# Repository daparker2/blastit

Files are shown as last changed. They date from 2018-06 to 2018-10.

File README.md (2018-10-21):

# blastit
OBD2 UART-based display controller done in Verilog and C based on a Cyclone3 core board and custom display.

Basically this addresses issues I had in my last OBD2 gauge panel thing like the display being too bright and reset times being too slow. Image of my final rev C board below as I test the display:

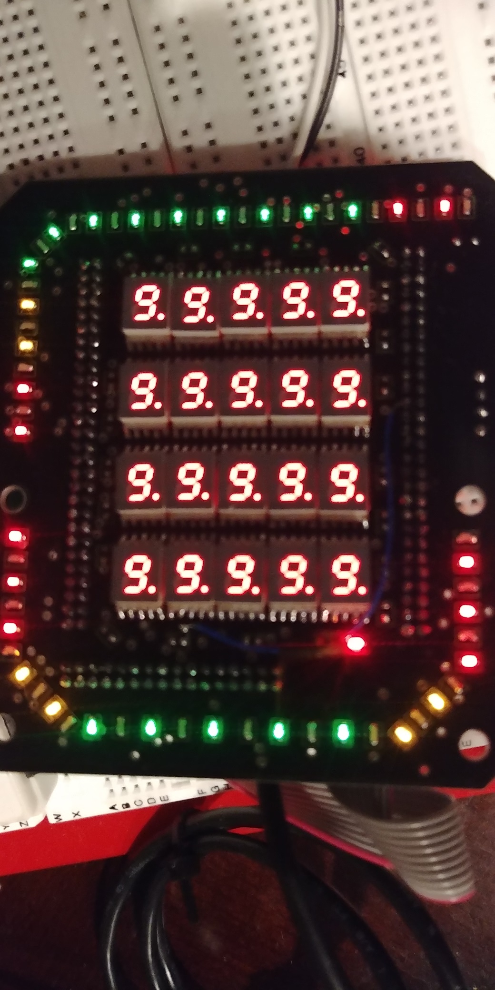
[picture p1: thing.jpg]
The thing


There is a UART and power input on the back which goes to a [Freematics OBD2](https://freematics.com/pages/products/freematics-obd-ii-uart-adapter-mk2/) ELM327 interface, and I have brought up the UART and display code already. FPGA is a [Waveshare Core3](https://www.waveshare.com/product/fpga-tools/altera/core/coreep3c16.htm). The code is mine and display is a pretty simple [2-layer PCB](https://github.com/daparker2/blastit/blob/master/doc/RevC.PDF) with a couple LED matrix bars and a central 20 digit readout. Now I am just writing the display task engine and OBD2 state machine and then it will just need a final mechanical enclosure which I am 3D printing; I am not totally happy with the one I have already printed.

Maybe one more update if I ever get it in my car, I have an STL file which I have 3D printed before but I will need to modify the model to make the fitment closer to the PCB and to work with an existing gauge fixture I have, cause removing double sided tape last time I reinstalled a gauge really tore up my dashboard. Haha.

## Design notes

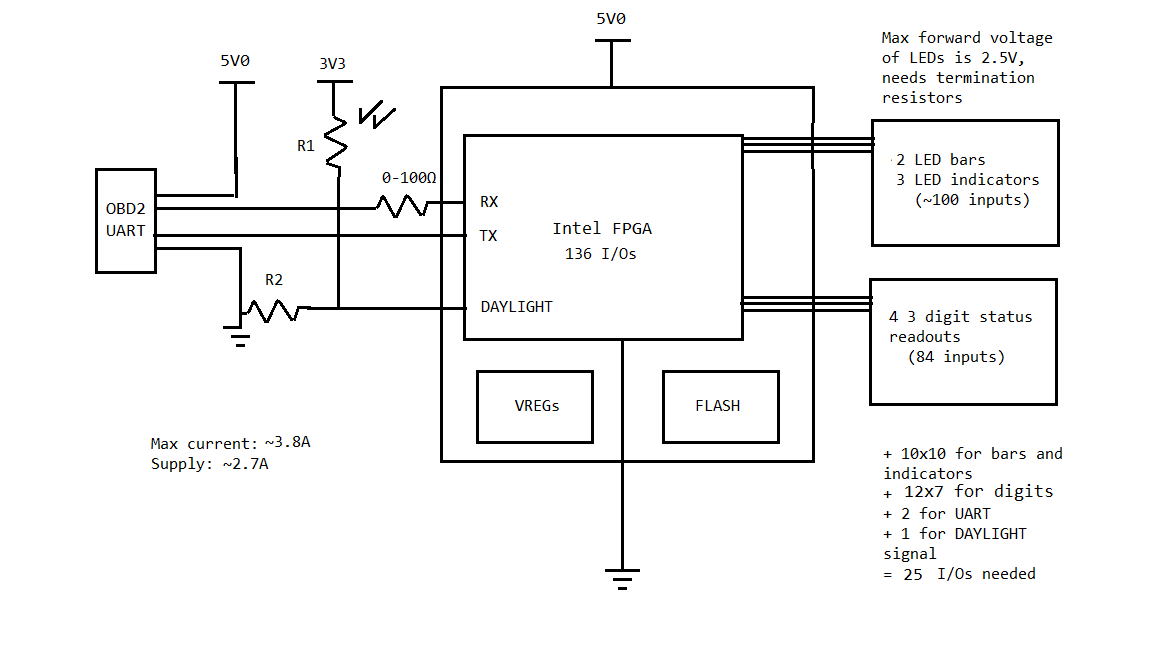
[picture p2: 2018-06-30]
doc/gauge2.png

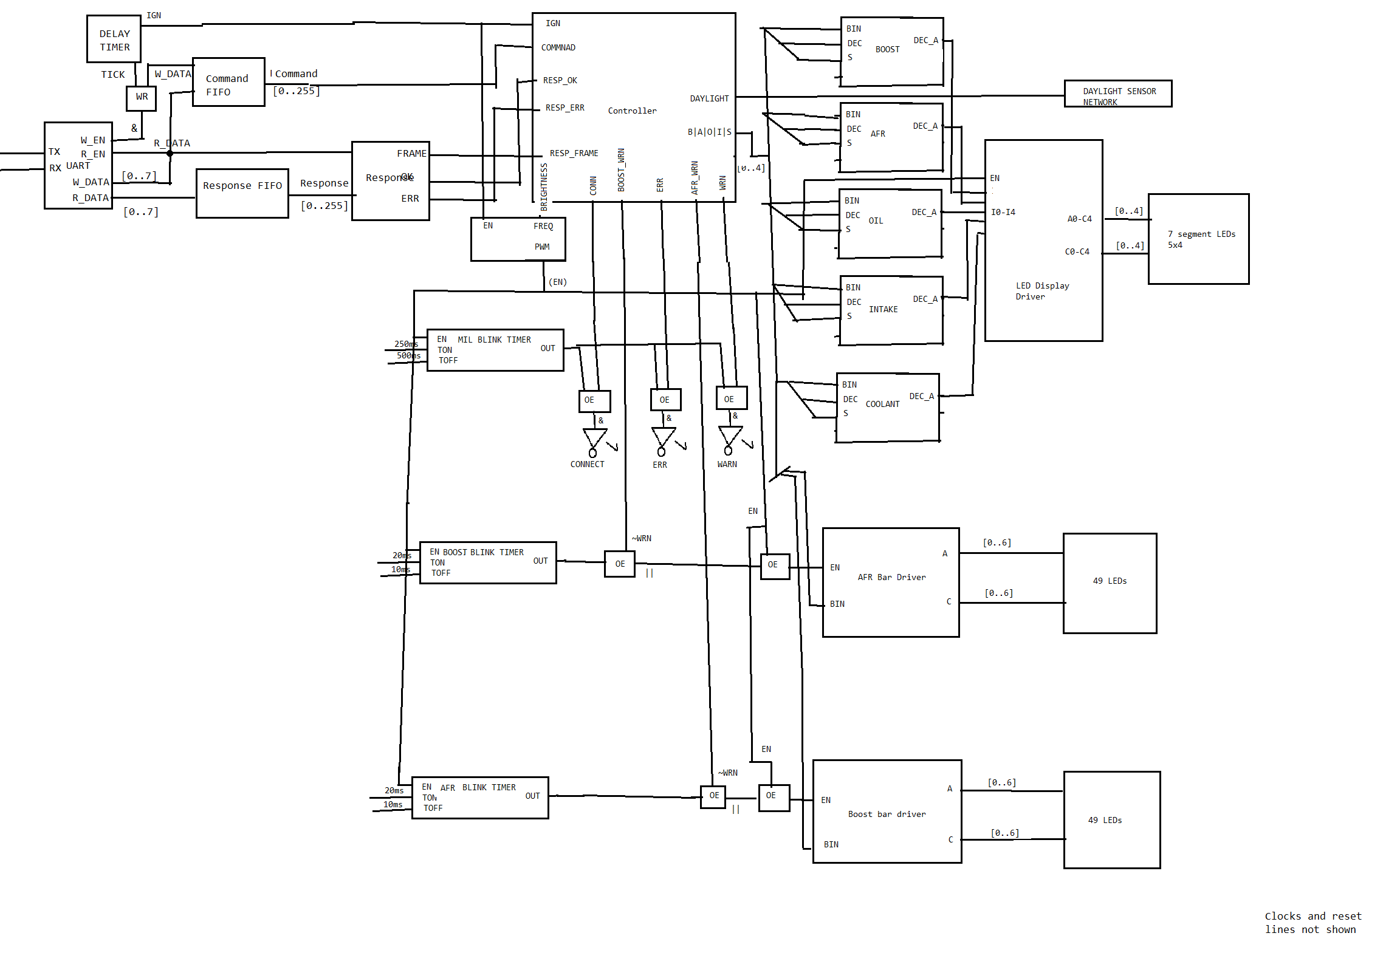
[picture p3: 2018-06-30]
doc/stack.png

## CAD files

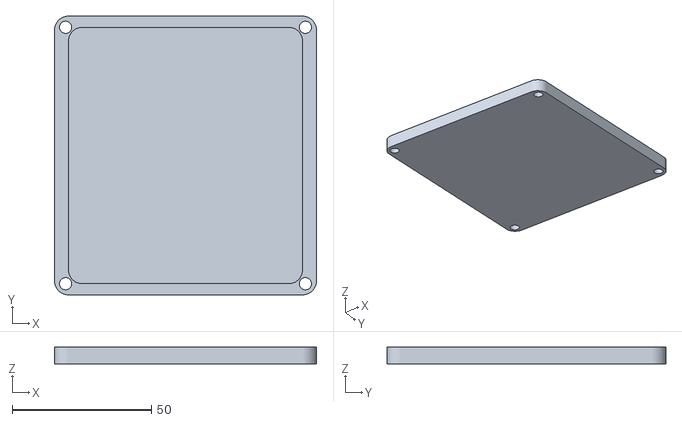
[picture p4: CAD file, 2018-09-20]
doc/Enclosure/Viewpane.stl
94.0 x 100.0 x 6.00

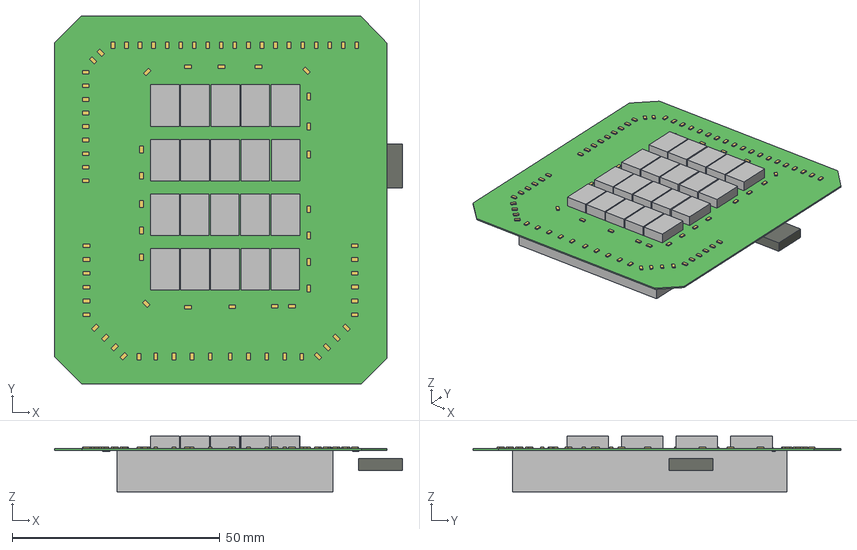
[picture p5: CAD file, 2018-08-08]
doc/RevC.step
83.7 x 88.5 x 13.4 mm
Board
Extruded x 111

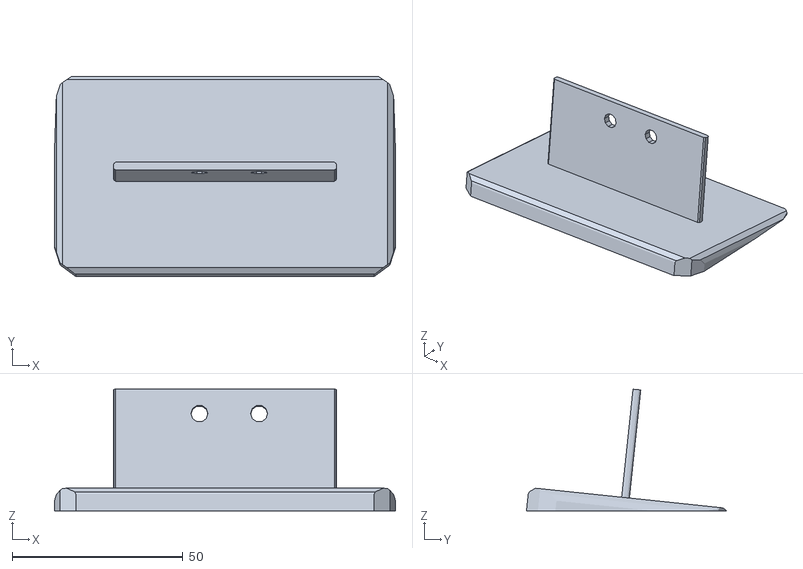
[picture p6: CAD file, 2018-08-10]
Enclosure/Base.stl
100.0 x 58.7 x 35.7

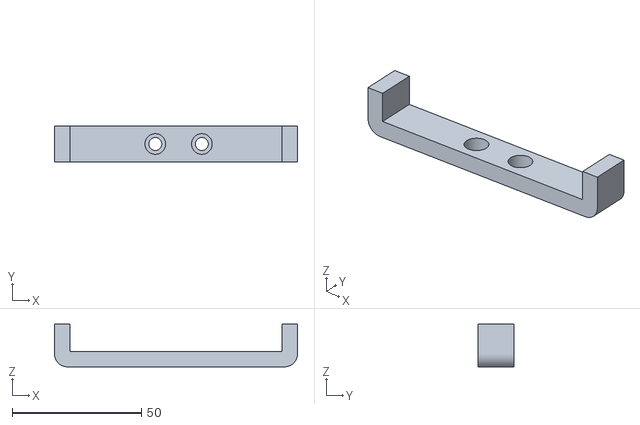
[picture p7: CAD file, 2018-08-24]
doc/Enclosure/Connector.stl
94.0 x 14.0 x 16.5

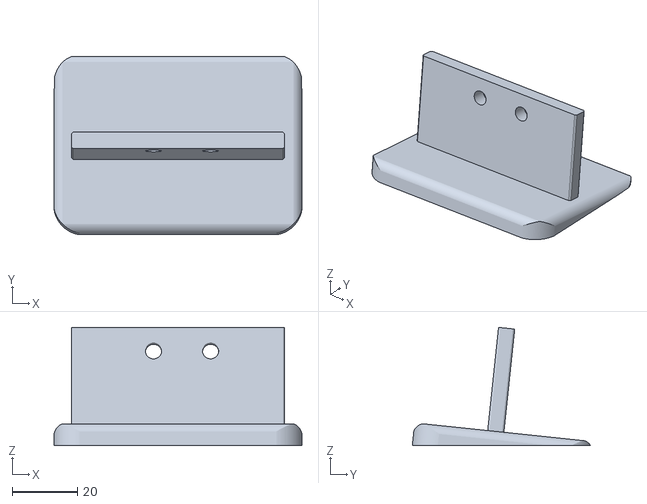
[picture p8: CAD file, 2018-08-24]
doc/Enclosure/Base.stl
76.0 x 54.7 x 36.2

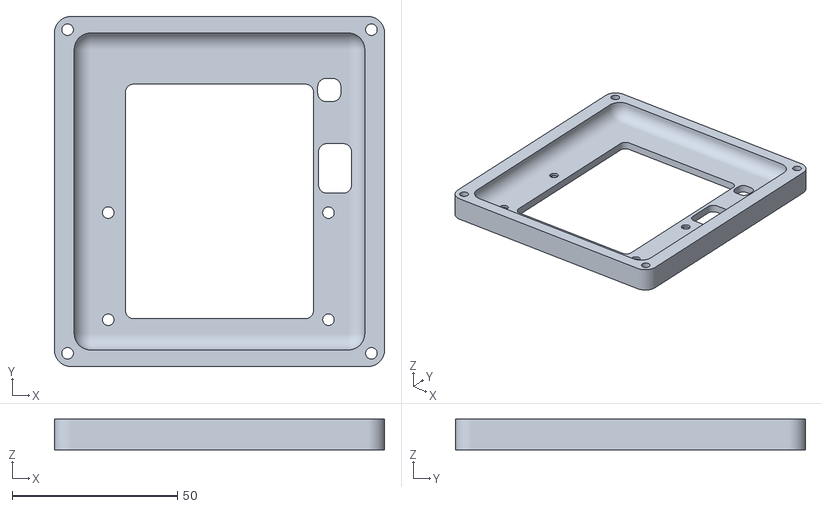
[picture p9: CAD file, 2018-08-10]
doc/Enclosure/Back.stl
100.0 x 106.0 x 9.38

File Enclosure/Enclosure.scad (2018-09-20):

// Module enclosure for proejct

// Subdivision resolution
FN_ROUND=200;
//FN_ROUND=10;
FN_HEX=6;

// Hex nut
HEX_NUT_WIDTH=7;
HEX_NUT_HEIGHT=3;

//PCB
PCB_OFFSET_Z=-6;

// PCB drill hole
PCB_HOLE_WIDTH=3.5;
PCB_HOLE_HEIGHT=50;
PCB_HOLE_OFFSET_X1=32;
PCB_HOLE_OFFSET_X2=34.7;
PCB_HOLE_OFFSET_Y1=-8.9;
PCB_HOLE_OFFSET_Y2=-41.33;

// Clamshell back
CLAMSHELL_INNER_X=74;
CLAMSHELL_INNER_Y=82;
CLAMSHELL_INNER_Z=5;
CLAMSHELL_OUTER_X=84;
CLAMSHELL_OUTER_Y=90;
CLAMSHELL_OUTER_Z=20;
CLAMSHELL_ROUND_W=10;
CLAMSHELL_BACK_Z=18;

// Clamshell back cutout
CLAMSHELL_CUTOUT1_X=5;
CLAMSHELL_CUTOUT1_Y=10;
CLAMSHELL_CUTOUT1_OFFSET_X=35;
CLAMSHELL_CUTOUT1_OFFSET_Y=7;
CLAMSHELL_CUTOUT2_X=52;
CLAMSHELL_CUTOUT2_Y=66;
CLAMSHELL_CUTOUT2_OFFSET_X=0;
CLAMSHELL_CUTOUT2_OFFSET_Y=-3;
CLAMSHELL_CUTOUT3_X=2;
CLAMSHELL_CUTOUT3_Y=2;
CLAMSHELL_CUTOUT3_OFFSET_X=33.25;
CLAMSHELL_CUTOUT3_OFFSET_Y=30.75;
CLAMSHELL_CUTOUT_ROUND_W=5;
CLAMSHELL_CUTOUT_Z=30;
CLAMSHELL_CUTOUT_OFFSET_Z=-10;
CLAMSHELL_VIEWPANE_SCALE_Z=5;
CLAMSHELL_CUTOUT_OFFSET_X=1;
CLAMSHELL_CUTOUT_OFFSET_Y=2.5;

// Clamshell viewpane drill holes
VIEWPANE_HOLE_WIDTH=3.5;
VIEWPANE_HOLE_HEIGHT=50;
VIEWPANE_HOLE_OFFSET_X1=43;
VIEWPANE_HOLE_OFFSET_X2=43;
VIEWPANE_HOLE_OFFSET_Y1=46;
VIEWPANE_HOLE_OFFSET_Y2=-46;
VIEWPANE_HOLE_SCALE = 1.25;
VIEWPANE_COVER_Z=1;
VIEWPANE_SKIRT_Z=3; // Skirt around ICs that are now sticking out...

// Clamshell front
CLAMSHELL_VIEWPANE_Z=3;

// Clamshell connector
CLAMSHELL_CONNECTOR_OUTER_X=CLAMSHELL_OUTER_X+.001;
CLAMSHELL_CONNECTOR_OUTER_Y=7;
CLAMSHELL_CONNECTOR_OUTER_Z=13;
CLAMSHELL_CONNECTOR_INNER_X=CLAMSHELL_CONNECTOR_OUTER_X-2;
CLAMSHELL_CONNECTOR_INNER_Y=CLAMSHELL_CONNECTOR_OUTER_Y+100;
CLAMSHELL_CONNECTOR_INNER_Z=CLAMSHELL_CONNECTOR_OUTER_Z+8;
CLAMSHELL_CONNECTOR_INNER_OFFSET_Z=5;
CLAMSHELL_CONNECTOR_OFFSET_X=0;
CLAMSHELL_CONNECTOR_OFFSET_Y=-27;
CLAMSHELL_CONNECTOR_OFFSET_Z=-12;
CLAMSHELL_CONNECTOR_CUTOFF_X=100;
CLAMSHELL_CONNECTOR_CUTOFF_Y=60;
CLAMSHELL_CONNECTOR_CUTOFF_Z=18;
CLAMSHELL_CONNECTOR_CUTOFF_OFFSET_Z=14;
CLAMSHELL_CONNECTOR_ROUND_W=5;

// Clamshell connector holes
CLAMSHELL_CONNECTOR_HOLE_OFFSET_X=-8;
CLAMSHELL_CONNECTOR_HOLE_OFFSET_Y=-30.5;
CLAMSHELL_CONNECTOR_HOLE_OFFSET_Z=-14;
CLAMSHELL_CONNECTOR_INNER_HOLE_H=100;
CLAMSHELL_CONNECTOR_INNER_HOLE_RADIUS=2.5;
CLAMSHELL_CONNECTOR_OUTER_HOLE_H=16;
CLAMSHELL_CONNECTOR_OUTER_HOLE_RADIUS=4;
CLAMSHELL_CONNECTOR_HOLE_WIDTH=18;

// Clamshell base
CLAMSHELL_BASE_ANGLE=84;
CLAMSHELL_BASE_OFFSET_X=-50;
CLAMSHELL_BASE_OFFSET_Y=-62;
CLAMSHELL_BASE_OFFSET_Z=-10;

// Demo
DEMO_BASE_ANGLE=84;

module board() {
	color("Green", 1.0) {
		translate([CLAMSHELL_CUTOUT_OFFSET_X,CLAMSHELL_CUTOUT_OFFSET_Y,PCB_OFFSET_Z]) {
			import("RevC.stl");
		}
	}
}

module base() {
	color("Magenta", 1.0) {
		translate([CLAMSHELL_BASE_OFFSET_X, CLAMSHELL_BASE_OFFSET_Y, CLAMSHELL_BASE_OFFSET_Z])
		rotate([-CLAMSHELL_BASE_ANGLE, 0, 0])
			import("Base.stl");
	}
}
		

// Drill hole 3d bodies
module drill_holes() {
	translate([PCB_HOLE_OFFSET_X1,0,-PCB_HOLE_HEIGHT/2]) {
		translate([0,PCB_HOLE_OFFSET_Y1,0])
			cylinder(r=PCB_HOLE_WIDTH/2, h=PCB_HOLE_HEIGHT, $fn=FN_ROUND);
		translate([0,PCB_HOLE_OFFSET_Y2,0])
			cylinder(r=PCB_HOLE_WIDTH/2, h=PCB_HOLE_HEIGHT, $fn=FN_ROUND);
	}

	translate([-PCB_HOLE_OFFSET_X2,0,-PCB_HOLE_HEIGHT/2]) {
		translate([0,PCB_HOLE_OFFSET_Y1,0])
			cylinder(r=PCB_HOLE_WIDTH/2, h=PCB_HOLE_HEIGHT, $fn=FN_ROUND);
		translate([0,PCB_HOLE_OFFSET_Y2,0])
			cylinder(r=PCB_HOLE_WIDTH/2, h=PCB_HOLE_HEIGHT, $fn=FN_ROUND);
	}
}

module hex_nut_holes() {
	translate([PCB_HOLE_OFFSET_X1,0,0]) {
		translate([0,PCB_HOLE_OFFSET_Y1,0])
			cylinder(r=HEX_NUT_WIDTH/2, h=HEX_NUT_HEIGHT, $fn=FN_HEX);
		translate([0,PCB_HOLE_OFFSET_Y2,0])
			cylinder(r=HEX_NUT_WIDTH/2, h=HEX_NUT_HEIGHT, $fn=FN_HEX);
	}

	translate([-PCB_HOLE_OFFSET_X2,0,0]) {
		translate([0,PCB_HOLE_OFFSET_Y1,0])
			cylinder(r=HEX_NUT_WIDTH/2, h=HEX_NUT_HEIGHT, $fn=FN_HEX);
		translate([0,PCB_HOLE_OFFSET_Y2,0])
			cylinder(r=HEX_NUT_WIDTH/2, h=HEX_NUT_HEIGHT, $fn=FN_HEX);
	}
}

module clamshell_inner_region() {
	minkowski() {
		cube([CLAMSHELL_INNER_X, CLAMSHELL_INNER_Y, CLAMSHELL_INNER_Z], center=true);
		sphere(r=CLAMSHELL_ROUND_W/2, center=true, $fn=FN_ROUND);
	}
}

module clamshell_outer_region() {
	minkowski() {
		cube([CLAMSHELL_OUTER_X, CLAMSHELL_OUTER_Y, CLAMSHELL_OUTER_Z], center=true);
		cylinder(r=CLAMSHELL_ROUND_W/2, center=true, $fn=FN_ROUND);
	}
}

module clamshell_viewpane_region(viewpane_z) {
	minkowski() {
		cube([CLAMSHELL_OUTER_X, CLAMSHELL_OUTER_Y, viewpane_z], center=true);
		cylinder(r=CLAMSHELL_ROUND_W/2, center=true, $fn=FN_ROUND);
	}
}

// Drill holes for clamshell viewpane
module viewpane_drill_holes(viewpane_hole_scale) {
	if (!viewpane_hole_scale) {
		translate([VIEWPANE_HOLE_OFFSET_X1,0,-VIEWPANE_HOLE_HEIGHT/2]) {
			translate([0,VIEWPANE_HOLE_OFFSET_Y1,0])
				cylinder(r=VIEWPANE_HOLE_WIDTH/2, h=VIEWPANE_HOLE_HEIGHT, $fn=FN_ROUND);
			translate([0,VIEWPANE_HOLE_OFFSET_Y2,0])
				cylinder(r=VIEWPANE_HOLE_WIDTH/2, h=VIEWPANE_HOLE_HEIGHT, $fn=FN_ROUND);
		}

		translate([-VIEWPANE_HOLE_OFFSET_X2,0,-VIEWPANE_HOLE_HEIGHT/2]) {
			translate([0,VIEWPANE_HOLE_OFFSET_Y1,0])
				cylinder(r=VIEWPANE_HOLE_WIDTH/2, h=VIEWPANE_HOLE_HEIGHT, $fn=FN_ROUND);
			translate([0,VIEWPANE_HOLE_OFFSET_Y2,0])
				cylinder(r=VIEWPANE_HOLE_WIDTH/2, h=VIEWPANE_HOLE_HEIGHT, $fn=FN_ROUND);
		}
	} else {
		translate([VIEWPANE_HOLE_OFFSET_X1,0,-VIEWPANE_HOLE_HEIGHT/2]) {
			translate([0,VIEWPANE_HOLE_OFFSET_Y1,0])
				cylinder(r=(VIEWPANE_HOLE_WIDTH*VIEWPANE_HOLE_SCALE)/2, h=VIEWPANE_HOLE_HEIGHT, $fn=FN_ROUND);
			translate([0,VIEWPANE_HOLE_OFFSET_Y2,0])
				cylinder(r=(VIEWPANE_HOLE_WIDTH*VIEWPANE_HOLE_SCALE)/2, h=VIEWPANE_HOLE_HEIGHT, $fn=FN_ROUND);
		}

		translate([-VIEWPANE_HOLE_OFFSET_X2,0,-VIEWPANE_HOLE_HEIGHT/2]) {
			translate([0,VIEWPANE_HOLE_OFFSET_Y1,0])
				cylinder(r=(VIEWPANE_HOLE_WIDTH*VIEWPANE_HOLE_SCALE)/2, h=VIEWPANE_HOLE_HEIGHT, $fn=FN_ROUND);
			translate([0,VIEWPANE_HOLE_OFFSET_Y2,0])
				cylinder(r=(VIEWPANE_HOLE_WIDTH*VIEWPANE_HOLE_SCALE)/2, h=VIEWPANE_HOLE_HEIGHT, $fn=FN_ROUND);
		}
	}
}

module clamshell_back_cutout_region() {
	union() {
		// This is for the OBD2 connection
		translate([CLAMSHELL_CUTOUT1_OFFSET_X, CLAMSHELL_CUTOUT1_OFFSET_Y, CLAMSHELL_CUTOUT_OFFSET_Z]) {
			minkowski() {
				cube([CLAMSHELL_CUTOUT1_X, CLAMSHELL_CUTOUT1_Y, CLAMSHELL_CUTOUT_Z], center=true);
				sphere(r=CLAMSHELL_CUTOUT_ROUND_W/2, center=true, $fn=FN_ROUND);
			}
		}
		
		// This relief area for the FPGA module
		translate([CLAMSHELL_CUTOUT2_OFFSET_X, CLAMSHELL_CUTOUT2_OFFSET_Y, CLAMSHELL_CUTOUT_OFFSET_Z]) {
			minkowski() {
				cube([CLAMSHELL_CUTOUT2_X, CLAMSHELL_CUTOUT2_Y, CLAMSHELL_CUTOUT_Z], center=true);
				sphere(r=CLAMSHELL_CUTOUT_ROUND_W/2, center=true, $fn=FN_ROUND);
			}
		}
		
		// This is for the daylight sensor to poke out
		translate([CLAMSHELL_CUTOUT3_OFFSET_X, CLAMSHELL_CUTOUT3_OFFSET_Y, CLAMSHELL_CUTOUT_OFFSET_Z]) {
			minkowski() {
				cube([CLAMSHELL_CUTOUT3_X, CLAMSHELL_CUTOUT3_Y, CLAMSHELL_CUTOUT_Z], center=true);
				sphere(r=CLAMSHELL_CUTOUT_ROUND_W/2, center=true, $fn=FN_ROUND);
			}
		}
	}
}

module clamshell_back() {
	color("Blue", 1) {
		difference() {
			clamshell_outer_region();
			clamshell_inner_region();
			translate([0,0,CLAMSHELL_BACK_Z/2])
			scale([1.05, 1.05, CLAMSHELL_VIEWPANE_SCALE_Z])
				clamshell_viewpane_region(CLAMSHELL_VIEWPANE_Z);			
			viewpane_drill_holes(false);
			clamshell_back_cutout_region();
			clamshell_connector();
			translate([CLAMSHELL_CUTOUT_OFFSET_X, CLAMSHELL_CUTOUT_OFFSET_Y, 0]) {
				drill_holes();
				translate([0,0,-(CLAMSHELL_OUTER_Z+HEX_NUT_HEIGHT)/2])
					hex_nut_holes();
			}
		}
	}
}

module clamshell_viewpane() {
	color("Yellow", 0.25) {
		translate([0,0,10]) {
			difference() {
				union() {
					clamshell_viewpane_region(VIEWPANE_COVER_Z);
					translate([0,0,VIEWPANE_SKIRT_Z - 0.001])
						difference() {
							clamshell_viewpane_region(VIEWPANE_SKIRT_Z);
			clamshell_inner_region();
						}
				}
				viewpane_drill_holes(true);
			}
		}
	}
}

module clamshell_connector_holes() {
	// Add speed holes...
	translate([CLAMSHELL_CONNECTOR_HOLE_OFFSET_X, CLAMSHELL_CONNECTOR_HOLE_OFFSET_Y, CLAMSHELL_CONNECTOR_HOLE_OFFSET_Z]) {	
		union() {
			cylinder(r=CLAMSHELL_CONNECTOR_INNER_HOLE_RADIUS,h=CLAMSHELL_CONNECTOR_INNER_HOLE_H, $fn=FN_ROUND, center=true);
			cylinder(r=CLAMSHELL_CONNECTOR_OUTER_HOLE_RADIUS,h=CLAMSHELL_CONNECTOR_OUTER_HOLE_H, $fn=FN_ROUND, center=true);
		}
		
		translate([CLAMSHELL_CONNECTOR_HOLE_WIDTH,0,0]) 
		union() {
			cylinder(r=CLAMSHELL_CONNECTOR_INNER_HOLE_RADIUS,h=CLAMSHELL_CONNECTOR_INNER_HOLE_H, $fn=FN_ROUND, center=true);
			cylinder(r=CLAMSHELL_CONNECTOR_OUTER_HOLE_RADIUS,h=CLAMSHELL_CONNECTOR_OUTER_HOLE_H, $fn=FN_ROUND, center=true);
		}
	}
}
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

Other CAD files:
FPGA/blastit_main.stp
Enclosure/RevC.step
Enclosure/RevC.stl

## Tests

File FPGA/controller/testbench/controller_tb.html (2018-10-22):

controller_tb

2018.10.21.20:50:07 | Datasheet

Overview

controller_inst_clk_0 | controller_tb

Processor
controller_inst_nios2e Nios II 13.1
All Components
controller_inst_sysid_c001 altera_avalon_sysid_qsys 13.1
controller_inst_jtag_uart_0 altera_avalon_jtag_uart 13.1
controller_inst_nios2e altera_nios2_qsys 13.1
controller_inst_onchip_ram altera_avalon_onchip_memory2 13.1
controller_inst_daylight altera_avalon_pio 13.1
controller_inst_tc1_m altera_avalon_pio 13.1
controller_inst_tc2_m altera_avalon_pio 13.1
controller_inst_tc3_m altera_avalon_pio 13.1
controller_inst_tc4_m altera_avalon_pio 13.1
controller_inst_tc_reset_control altera_avalon_pio 13.1
controller_inst_tc1_status altera_avalon_pio 13.1
controller_inst_tc2_status altera_avalon_pio 13.1
controller_inst_tc3_status altera_avalon_pio 13.1
controller_inst_tc4_status altera_avalon_pio 13.1
controller_inst_uart1_w_data altera_avalon_pio 13.1
controller_inst_uart1_reset_control altera_avalon_pio 13.1
controller_inst_uart1_wr_control altera_avalon_pio 13.1
controller_inst_uart1_baud_control altera_avalon_pio 13.1
controller_inst_uart1_r_data altera_avalon_pio 13.1
controller_inst_uart1_rx_counter altera_avalon_pio 13.1
controller_inst_uart1_tx_counter altera_avalon_pio 13.1
controller_inst_uart1_status_control altera_avalon_pio 13.1
controller_inst_bcd1_bin altera_avalon_pio 13.1
controller_inst_bcd1_control altera_avalon_pio 13.1
controller_inst_bcd1_bcd altera_avalon_pio 13.1
controller_inst_bcd1_counter altera_avalon_pio 13.1
controller_inst_bcd1_status altera_avalon_pio 13.1
controller_inst_warn_pwm_brightness altera_avalon_pio 13.1
controller_inst_status_led_en altera_avalon_pio 13.1
controller_inst_warn_pwm_control altera_avalon_pio 13.1
controller_inst_sseg_brightness altera_avalon_pio 13.1
controller_inst_sseg_reset_control altera_avalon_pio 13.1
controller_inst_sseg_wr_val altera_avalon_pio 13.1
controller_inst_sseg_counter altera_avalon_pio 13.1
controller_inst_sseg_counter_of altera_avalon_pio 13.1
controller_inst_leds1_brightness altera_avalon_pio 13.1
controller_inst_leds1_reset_control altera_avalon_pio 13.1
controller_inst_leds1_wr_val altera_avalon_pio 13.1
controller_inst_leds1_counter altera_avalon_pio 13.1
controller_inst_leds1_counter_of altera_avalon_pio 13.1
controller_inst_uart1_dvsr altera_avalon_pio 13.1
controller_inst_rc1_control altera_avalon_pio 13.1
controller_inst_rc1_ready altera_avalon_pio 13.1
controller_inst_led_period altera_avalon_pio 13.1
controller_inst_leds2_reset_control altera_avalon_pio 13.1
controller_inst_leds2_wr_val altera_avalon_pio 13.1
controller_inst_leds2_counter altera_avalon_pio 13.1
controller_inst_leds2_counter_of altera_avalon_pio 13.1
controller_inst_leds2_brightness altera_avalon_pio 13.1

Memory Map

| controller_inst_nios2e
| data_master | instruction_master
controller_inst_sysid_c001
control_slave | 0x00011308 | 0x00011308
controller_inst_jtag_uart_0
avalon_jtag_slave | 0x00011300 | 0x00011300
controller_inst_nios2e
jtag_debug_module | 0x00010800 | 0x00010800
controller_inst_onchip_ram
s1 | 0x00000000 | 0x00000000
controller_inst_daylight
s1 | 0x000112e0
controller_inst_tc1_m
s1 | 0x000112d0
controller_inst_tc2_m
s1 | 0x000112c0
controller_inst_tc3_m
s1 | 0x000112b0
controller_inst_tc4_m
s1 | 0x000112a0
controller_inst_tc_reset_control
s1 | 0x00011290
controller_inst_tc1_status
s1 | 0x00011280
controller_inst_tc2_status
s1 | 0x00011270
controller_inst_tc3_status
s1 | 0x00011260
controller_inst_tc4_status
s1 | 0x00011250
controller_inst_uart1_w_data
s1 | 0x00011240
controller_inst_uart1_reset_control
s1 | 0x00011230
controller_inst_uart1_wr_control
s1 | 0x00011220
controller_inst_uart1_baud_control
s1 | 0x00011210
controller_inst_uart1_r_data
s1 | 0x00011200
controller_inst_uart1_rx_counter
s1 | 0x000111d0
controller_inst_uart1_tx_counter
s1 | 0x000111f0
controller_inst_uart1_status_control
s1 | 0x000111e0
controller_inst_bcd1_bin
s1 | 0x000111c0
controller_inst_bcd1_control
s1 | 0x000111b0
controller_inst_bcd1_bcd
s1 | 0x000111a0
controller_inst_bcd1_counter
s1 | 0x00011190
controller_inst_bcd1_status
s1 | 0x00011180
controller_inst_warn_pwm_brightness
s1 | 0x00011170
controller_inst_status_led_en
s1 | 0x00011000
controller_inst_warn_pwm_control
s1 | 0x00011160
controller_inst_sseg_brightness
s1 | 0x00011150
controller_inst_sseg_reset_control
s1 | 0x00011140
controller_inst_sseg_wr_val
s1 | 0x00011130
controller_inst_sseg_counter
s1 | 0x00011120
controller_inst_sseg_counter_of
s1 | 0x00011110
controller_inst_leds1_brightness
s1 | 0x00011100
controller_inst_leds1_reset_control
s1 | 0x000110f0
controller_inst_leds1_wr_val
s1 | 0x000110e0
controller_inst_leds1_counter
s1 | 0x000110d0
controller_inst_leds1_counter_of
s1 | 0x000110c0
controller_inst_uart1_dvsr
s1 | 0x000110b0
controller_inst_rc1_control
s1 | 0x000110a0
controller_inst_rc1_ready
s1 | 0x00011090
controller_inst_led_period
s1 | 0x00011080
controller_inst_leds2_reset_control
s1 | 0x00011070
controller_inst_leds2_wr_val
s1 | 0x00011060
controller_inst_leds2_counter
s1 | 0x00011050
controller_inst_leds2_counter_of
s1 | 0x00011040
controller_inst_leds2_brightness
s1 | 0x00011030

## controller_inst

controller v1.0

Parameters

AUTO_GENERATION_ID | 1540180207
AUTO_UNIQUE_ID | controller
AUTO_DEVICE_FAMILY | CYCLONEIII
AUTO_DEVICE | EP3C16Q240C8
AUTO_CLOCK_50_CLOCK_RATE | 0
AUTO_CLOCK_50_CLOCK_DOMAIN | 1
AUTO_CLOCK_50_RESET_DOMAIN | 1
deviceFamily | Cyclone III
generateLegacySim | false

Software Assignments
(none)

## controller_inst_clk_0

clock_source v13.1

controller_inst_clock_50_bfm | clk | controller_inst_clk_0
| clk_in
controller_inst_reset_bfm | reset
| clk_in_reset
| | | clk | controller_inst_sysid_c001
| | | clk
| | | clk_reset
| | | reset
| | | clk | controller_inst_jtag_uart_0
| | | clk
| | | clk_reset
| | | reset
| | | clk_reset | controller_inst_nios2e
| | | reset_n
| | | clk
| | | clk
| | | clk | controller_inst_onchip_ram
| | | clk1
| | | clk_reset
| | | reset1
| | | clk | controller_inst_daylight
| | | clk
| | | clk_reset
| | | reset
| | | clk | controller_inst_tc1_m
| | | clk
| | | clk_reset
| | | reset
| | | clk | controller_inst_tc2_m
| | | clk
| | | clk_reset
| | | reset
| | | clk | controller_inst_tc3_m
| | | clk
| | | clk_reset
| | | reset
| | | clk | controller_inst_tc4_m
| | | clk
| | | clk_reset
| | | reset
| | | clk | controller_inst_tc_reset_control
| | | clk
| | | clk_reset
| | | reset
| | | clk | controller_inst_tc1_status
| | | clk
| | | clk_reset
| | | reset
| | clk | controller_inst_tc2_status
| | clk
| | clk_reset
| | reset
| | clk | controller_inst_tc3_status
| | clk
| | clk_reset
| | reset
| | clk | controller_inst_tc4_status
| | clk
| | clk_reset
| | reset
| | clk | controller_inst_uart1_w_data
| | clk
| | clk_reset
| | reset
| | clk | controller_inst_uart1_reset_control
| | clk
| | clk_reset
| | reset
| | clk | controller_inst_uart1_wr_control
| | clk
| | clk_reset
| | reset
| | clk | controller_inst_uart1_baud_control
| | clk
| | clk_reset
| | reset
| | clk | controller_inst_uart1_r_data
| | clk
| | clk_reset
| | reset
| | clk | controller_inst_uart1_rx_counter
| | clk
| | clk_reset
| | reset
| | clk | controller_inst_uart1_tx_counter
| | clk
| | clk_reset
| | reset
| | clk | controller_inst_uart1_status_control
| | clk
| | clk_reset
| | reset
| | clk | controller_inst_bcd1_bin
| | clk
| | clk_reset
| | reset
| | clk | controller_inst_bcd1_control
| | clk
| | clk_reset
| | reset
| | clk | controller_inst_bcd1_bcd
| | clk
| | clk_reset
| | reset
| | clk | controller_inst_bcd1_counter
| | clk
| | clk_reset
| | reset
| | clk | controller_inst_bcd1_status
| | clk
| | clk_reset
| | reset
| | clk | controller_inst_warn_pwm_brightness
| | clk
| | clk_reset
| | reset
| | clk | controller_inst_warn_pwm_control
| | clk
| | clk_reset
| | reset
| | clk | controller_inst_status_led_en
| | clk
| | clk_reset
| | reset
| | clk | controller_inst_sseg_brightness
| | clk
| | clk_reset
| | reset
| | clk | controller_inst_sseg_reset_control
| | clk
| | clk_reset
| | reset
| | clk | controller_inst_sseg_wr_val
| | clk
| | clk_reset
| | reset
| | clk | controller_inst_sseg_counter
| | clk
| | clk_reset
| | reset
| | clk | controller_inst_sseg_counter_of
| | clk
| | clk_reset
| | reset
| | clk | controller_inst_leds1_brightness
| | clk
| | clk_reset
| | reset
| | clk | controller_inst_leds1_reset_control
| | clk
| | clk_reset
| | reset
| | clk | controller_inst_leds1_wr_val
| | clk
| | clk_reset
| | reset
| | clk | controller_inst_leds1_counter
| | clk
| | clk_reset
| | reset
| | clk | controller_inst_leds1_counter_of
| | clk
| | clk_reset
| | reset
| | clk | controller_inst_uart1_dvsr
| | clk
| | clk_reset
| | reset
| | clk | controller_inst_rc1_control
| | clk
| | clk_reset
| | reset
| | clk | controller_inst_rc1_ready
| | clk
| | clk_reset
| | reset
| | clk | controller_inst_led_period
| | clk
| | clk_reset
| | reset
| | clk | controller_inst_leds2_reset_control
| | clk
| | clk_reset
| | reset
| | clk | controller_inst_leds2_wr_val
| | clk
| | clk_reset
| | reset
| | clk_reset | controller_inst_leds2_counter
| | reset
| | clk
| | clk
| | clk | controller_inst_leds2_counter_of
| | clk
| | clk_reset
| | reset
| | clk | controller_inst_leds2_brightness
| | clk
| | clk_reset
| | reset

Parameters

clockFrequency | 50000000
clockFrequencyKnown | true
inputClockFrequency | 0
resetSynchronousEdges | NONE
deviceFamily | UNKNOWN
generateLegacySim | false

Software Assignments
(none)

## controller_inst_sysid_c001

altera_avalon_sysid_qsys v13.1

controller_inst_clk_0 | clk | controller_inst_sysid_c001
| clk
| clk_reset
| reset
controller_inst_nios2e | data_master
| control_slave
| jtag_debug_module_reset
| reset
| instruction_master
| control_slave

Parameters

id | 49153
timestamp | 1540180207
AUTO_CLK_CLOCK_RATE | 50000000
AUTO_DEVICE_FAMILY | CYCLONEIII
deviceFamily | Cyclone III
generateLegacySim | false

Software Assignments

ID | 49153
TIMESTAMP | 1540180207

## controller_inst_jtag_uart_0

altera_avalon_jtag_uart v13.1

controller_inst_clk_0 | clk | controller_inst_jtag_uart_0
| clk
| clk_reset
| reset
controller_inst_nios2e | data_master
| avalon_jtag_slave
| d_irq
| irq
| jtag_debug_module_reset
| reset
| instruction_master
| avalon_jtag_slave

Parameters

allowMultipleConnections | true
hubInstanceID | 0
readBufferDepth | 32
readIRQThreshold | 8
simInputCharacterStream
simInteractiveOptions | NO_INTERACTIVE_WINDOWS
useRegistersForReadBuffer | false
useRegistersForWriteBuffer | false
useRelativePathForSimFile | false
writeBufferDepth | 256
writeIRQThreshold | 8
avalonSpec | 2.0
legacySignalAllow | false
enableInteractiveInput | false
enableInteractiveOutput | false
deviceFamily | UNKNOWN
generateLegacySim | false

Software Assignments

READ_DEPTH | 32
READ_THRESHOLD | 8
WRITE_DEPTH | 256
WRITE_THRESHOLD | 8

## controller_inst_nios2e

altera_nios2_qsys v13.1

controller_inst_clk_0 | clk_reset | controller_inst_nios2e
| reset_n
| clk
| clk
| | | data_master | controller_inst_sysid_c001
| | | control_slave
| | | jtag_debug_module_reset
| | | reset
| | | instruction_master
| | | control_slave
| | | data_master | controller_inst_jtag_uart_0
| | | avalon_jtag_slave
| | | d_irq
| | | irq
| | | jtag_debug_module_reset
| | | reset
| | | instruction_master
| | | avalon_jtag_slave
| | | instruction_master | controller_inst_onchip_ram
| | | s1
| | | data_master
| | | s1
| | | jtag_debug_module_reset
| | | reset1
| | | data_master | controller_inst_daylight
| | | s1
| | | jtag_debug_module_reset
| | | reset
| | | d_irq
| | | irq
| | | data_master | controller_inst_tc1_m
| | | s1
| | | jtag_debug_module_reset
| | | reset
| | | data_master | controller_inst_tc2_m
| | | s1
| | | jtag_debug_module_reset
| | | reset
| | | data_master | controller_inst_tc3_m
| | | s1
| | | jtag_debug_module_reset
| | | reset
| | | data_master | controller_inst_tc4_m
| | | s1
| | | jtag_debug_module_reset
| | | reset
| | | data_master | controller_inst_tc_reset_control
| | | s1
| | | jtag_debug_module_reset
| | | reset
| | | data_master | controller_inst_tc1_status
| | s1
| | jtag_debug_module_reset
| | reset
| | data_master | controller_inst_tc2_status
| | s1
| | jtag_debug_module_reset
| | reset
| | data_master | controller_inst_tc3_status
| | s1
| | jtag_debug_module_reset
| | reset
| | data_master | controller_inst_tc4_status
| | s1
| | jtag_debug_module_reset
| | reset
| | data_master | controller_inst_uart1_w_data
| | s1
| | jtag_debug_module_reset
| | reset
| | data_master | controller_inst_uart1_reset_control
| | s1
| | jtag_debug_module_reset
| | reset
| | data_master | controller_inst_uart1_wr_control
| | s1
| | jtag_debug_module_reset
| | reset
| | data_master | controller_inst_uart1_baud_control
| | s1
| | jtag_debug_module_reset
| | reset
| | data_master | controller_inst_uart1_r_data
| | s1
| | jtag_debug_module_reset
| | reset
| | data_master | controller_inst_uart1_tx_counter
| | s1
| | jtag_debug_module_reset
| | reset
| | data_master | controller_inst_uart1_status_control
| | s1
| | jtag_debug_module_reset
| | reset
| | data_master | controller_inst_uart1_rx_counter
| | s1
| | jtag_debug_module_reset
| | reset
| | data_master | controller_inst_bcd1_bin
| | s1
| | jtag_debug_module_reset
| | reset
| | data_master | controller_inst_bcd1_control
| | s1
| | jtag_debug_module_reset
| | reset
| | data_master | controller_inst_bcd1_bcd
| | s1
| | jtag_debug_module_reset
| | reset
| | data_master | controller_inst_bcd1_counter
| | s1
| | jtag_debug_module_reset
| | reset
| | data_master | controller_inst_bcd1_status
| | s1
| | jtag_debug_module_reset
| | reset
| | data_master | controller_inst_warn_pwm_brightness
| | s1
| | jtag_debug_module_reset
| | reset
| | data_master | controller_inst_warn_pwm_control
| | s1
| | jtag_debug_module_reset
| | reset
| | data_master | controller_inst_status_led_en
| | s1
| | jtag_debug_module_reset
| | reset
| | data_master | controller_inst_sseg_brightness
| | s1
| | jtag_debug_module_reset
| | reset
| | data_master | controller_inst_sseg_reset_control
| | s1
| | jtag_debug_module_reset
| | reset
| | data_master | controller_inst_sseg_wr_val
| | s1
| | jtag_debug_module_reset
| | reset
| | data_master | controller_inst_sseg_counter
| | s1
| | jtag_debug_module_reset
| | reset
| | data_master | controller_inst_sseg_counter_of
| | s1
| | jtag_debug_module_reset
| | reset
| | data_master | controller_inst_leds1_brightness
| | s1
| | jtag_debug_module_reset
| | reset
| | data_master | controller_inst_leds1_reset_control
| | s1
| | jtag_debug_module_reset
| | reset
| | data_master | controller_inst_leds1_wr_val
| | s1
| | jtag_debug_module_reset
| | reset
| | data_master | controller_inst_leds1_counter
| | s1
| | jtag_debug_module_reset
| | reset
| | data_master | controller_inst_leds1_counter_of
| | s1
| | jtag_debug_module_reset
| | reset
| | data_master | controller_inst_uart1_dvsr
| | s1
| | jtag_debug_module_reset
| | reset
| | data_master | controller_inst_rc1_control
| | s1
| | jtag_debug_module_reset
| | reset
| | data_master | controller_inst_rc1_ready
| | s1
| | jtag_debug_module_reset
| | reset
| | d_irq
| | irq
| | data_master | controller_inst_led_period
| | s1
| | jtag_debug_module_reset
| | reset
| | jtag_debug_module_reset | controller_inst_leds2_reset_control
| | reset
| | data_master
| | s1
| | jtag_debug_module_reset | controller_inst_leds2_wr_val
| | reset
| | data_master
| | s1
| | jtag_debug_module_reset | controller_inst_leds2_counter
| | reset
| | data_master
| | s1
| | jtag_debug_module_reset | controller_inst_leds2_counter_of
| | reset
| | data_master
| | s1
| | jtag_debug_module_reset | controller_inst_leds2_brightness
| | reset
| | data_master
| | s1

Parameters

setting_showUnpublishedSettings | false
setting_showInternalSettings | false
setting_preciseSlaveAccessErrorException | false
setting_preciseIllegalMemAccessException | false
setting_preciseDivisionErrorException | false
setting_performanceCounter | false
setting_illegalMemAccessDetection | false
setting_illegalInstructionsTrap | true
setting_fullWaveformSignals | false
setting_extraExceptionInfo | false
setting_exportPCB | false
setting_debugSimGen | false
setting_clearXBitsLDNonBypass | true
setting_bit31BypassDCache | true
setting_bigEndian | false
setting_export_large_RAMs | false
setting_asic_enabled | false
setting_asic_synopsys_translate_on_off | false
setting_oci_export_jtag_signals | false
setting_bhtIndexPcOnly | false
setting_avalonDebugPortPresent | false
setting_alwaysEncrypt | true
setting_allowFullAddressRange | false
setting_activateTrace | true
setting_activateTrace_user | false
setting_activateTestEndChecker | false
setting_ecc_sim_test_ports | false
setting_activateMonitors | true
setting_activateModelChecker | false
setting_HDLSimCachesCleared | true
setting_HBreakTest | false
setting_breakslaveoveride | false
muldiv_divider | true
mpu_useLimit | false
mpu_enabled | false
mmu_enabled | false
mmu_autoAssignTlbPtrSz | true
manuallyAssignCpuID | true
debug_triggerArming | true
debug_embeddedPLL | true
debug_debugReqSignals | false
debug_assignJtagInstanceID | false
dcache_omitDataMaster | false
cpuReset | false
is_hardcopy_compatible | false
setting_shadowRegisterSets | 0
mpu_numOfInstRegion | 8
mpu_numOfDataRegion | 8
mmu_TLBMissExcOffset | 0
debug_jtagInstanceID | 0
resetOffset | 0
exceptionOffset | 32
cpuID | 49153
cpuID_stored | 49153
breakOffset | 32
userDefinedSettings
resetSlave | Absolute
mmu_TLBMissExcSlave | None
exceptionSlave | Absolute
breakSlave | controller_inst_nios2e.jtag_debug_module
setting_perfCounterWidth | 32
setting_interruptControllerType | Internal
setting_branchPredictionType | Automatic
setting_bhtPtrSz | 8
muldiv_multiplierType | EmbeddedMulFast
mpu_minInstRegionSize | 12
mpu_minDataRegionSize | 12
mmu_uitlbNumEntries | 4
mmu_udtlbNumEntries | 6
mmu_tlbPtrSz | 7
mmu_tlbNumWays | 16
mmu_processIDNumBits | 8
impl | Tiny
icache_size | 512
icache_tagramBlockType | Automatic
icache_ramBlockType | Automatic
icache_numTCIM | 0
icache_burstType | Sequential
dcache_bursts | false
dcache_victim_buf_impl | ram
debug_level | Level1
debug_OCIOnchipTrace | _128
dcache_size | 2048
dcache_tagramBlockType | Automatic
dcache_ramBlockType | Automatic
dcache_numTCDM | 0
dcache_lineSize | 32
setting_exportvectors | false
setting_ecc_present | false
setting_ic_ecc_present | true
setting_rf_ecc_present | true
setting_mmu_ecc_present | true
setting_dc_ecc_present | false
setting_itcm_ecc_present | false
setting_dtcm_ecc_present | false
regfile_ramBlockType | Automatic
ocimem_ramBlockType | Automatic
mmu_ramBlockType | Automatic
bht_ramBlockType | Automatic
resetAbsoluteAddr | 0
exceptionAbsoluteAddr | 32
breakAbsoluteAddr | 67616
mmu_TLBMissExcAbsAddr | 0
dcache_bursts_derived | false
dcache_size_derived | 2048
dcache_lineSize_derived | 32
translate_on | "synthesis translate_on"
translate_off | "synthesis translate_off"
instAddrWidth | 17
dataAddrWidth | 17
tightlyCoupledDataMaster0AddrWidth | 1
tightlyCoupledDataMaster1AddrWidth | 1
tightlyCoupledDataMaster2AddrWidth | 1
tightlyCoupledDataMaster3AddrWidth | 1
tightlyCoupledInstructionMaster0AddrWidth | 1
tightlyCoupledInstructionMaster1AddrWidth | 1
tightlyCoupledInstructionMaster2AddrWidth | 1
tightlyCoupledInstructionMaster3AddrWidth | 1
instSlaveMapParam | <address-map><slave name='onchip_ram.s1' start='0x0' end='0x9C40' /><slave name='nios2e.jtag_debug_module' start='0x10800' end='0x11000' /><slave name='jtag_uart_0.avalon_jtag_slave' start='0x11300' end='0x11308' /><slave name='sysid_c001.control_slave' start='0x11308' end='0x11310' /></address-map>

dataSlaveMapParam

<address-map><slave name='onchip_ram.s1' start='0x0' end='0x9C40' /><slave name='nios2e.jtag_debug_module' start='0x10800' end='0x11000' /><slave name='status_led_en.s1' start='0x11000' end='0x11020' /><slave name='leds2_brightness.s1' start='0x11030' end='0x11040' /><slave name='leds2_counter_of.s1' start='0x11040' end='0x11050' /><slave name='leds2_counter.s1' start='0x11050' end='0x11060' /><slave name='leds2_wr_val.s1' start='0x11060' end='0x11070' /><slave name='leds2_reset_control.s1' start='0x11070' end='0x11080' /><slave name='led_period.s1' start='0x11080' end='0x11090' /><slave name='rc1_ready.s1' start='0x11090' end='0x110A0' /><slave name='rc1_control.s1' start='0x110A0' end='0x110B0' /><slave name='uart1_dvsr.s1' start='0x110B0' end='0x110C0' /><slave name='leds1_counter_of.s1' start='0x110C0' end='0x110D0' /><slave name='leds1_counter.s1' start='0x110D0' end='0x110E0' /><slave name='leds1_wr_val.s1' start='0x110E0' end='0x110F0' /><slave name='leds1_reset_control.s1' start='0x110F0' end='0x11100' /><slave name='leds1_brightness.s1' start='0x11100' end='0x11110' /><slave name='sseg_counter_of.s1' start='0x11110' end='0x11120' /><slave name='sseg_counter.s1' start='0x11120' end='0x11130' /><slave name='sseg_wr_val.s1' start='0x11130' end='0x11140' /><slave name='sseg_reset_control.s1' start='0x11140' end='0x11150' /><slave name='sseg_brightness.s1' start='0x11150' end='0x11160' /><slave name='warn_pwm_control.s1' start='0x11160' end='0x11170' /><slave name='warn_pwm_brightness.s1' start='0x11170' end='0x11180' /><slave name='bcd1_status.s1' start='0x11180' end='0x11190' /><slave name='bcd1_counter.s1' start='0x11190' end='0x111A0' /><slave name='bcd1_bcd.s1' start='0x111A0' end='0x111B0' /><slave name='bcd1_control.s1' start='0x111B0' end='0x111C0' /><slave name='bcd1_bin.s1' start='0x111C0' end='0x111D0' /><slave name='uart1_rx_counter.s1' start='0x111D0' end='0x111E0' /><slave name='uart1_status_control.s1' start='0x111E0' end='0x111F0' /><slave name='uart1_tx_counter.s1' start='0x111F0' end='0x11200' /><slave name='uart1_r_data.s1' start='0x11200' end='0x11210' /><slave name='uart1_baud_control.s1' start='0x11210' end='0x11220' /><slave name='uart1_wr_control.s1' start='0x11220' end='0x11230' /><slave name='uart1_reset_control.s1' start='0x11230' end='0x11240' /><slave name='uart1_w_data.s1' start='0x11240' end='0x11250' /><slave name='tc4_status.s1' start='0x11250' end='0x11260' /><slave name='tc3_status.s1' start='0x11260' end='0x11270' /><slave name='tc2_status.s1' start='0x11270' end='0x11280' /><slave name='tc1_status.s1' start='0x11280' end='0x11290' /><slave name='tc_reset_control.s1' start='0x11290' end='0x112A0' /><slave name='tc4_m.s1' start='0x112A0' end='0x112B0' /><slave name='tc3_m.s1' start='0x112B0' end='0x112C0' /><slave name='tc2_m.s1' start='0x112C0' end='0x112D0' /><slave name='tc1_m.s1' start='0x112D0' end='0x112E0' /><slave name='daylight.s1' start='0x112E0' end='0x112F0' /><slave name='jtag_uart_0.avalon_jtag_slave' start='0x11300' end='0x11308' /><slave name='sysid_c001.control_slave' start='0x11308' end='0x11310' /></address-map>
clockFrequency | 50000000
deviceFamilyName | CYCLONEIII
internalIrqMaskSystemInfo | 7
customInstSlavesSystemInfo | <info/>

deviceFeaturesSystemInfo
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

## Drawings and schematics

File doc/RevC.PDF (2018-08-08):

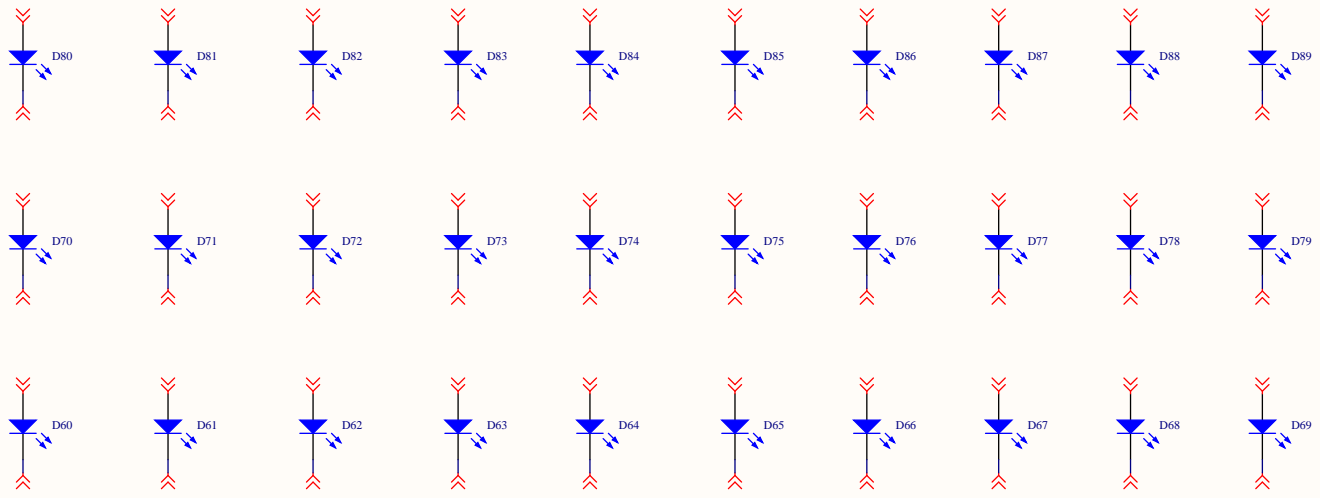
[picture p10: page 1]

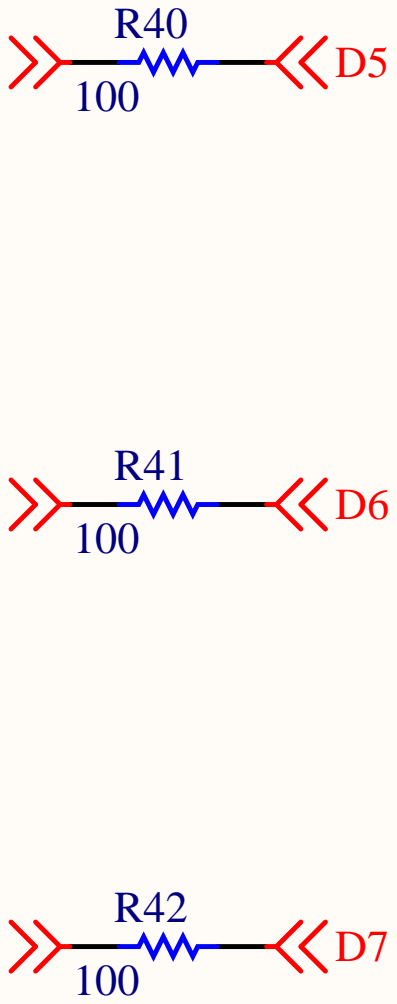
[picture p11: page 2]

AFR BAR TERMINATION RESISTORS

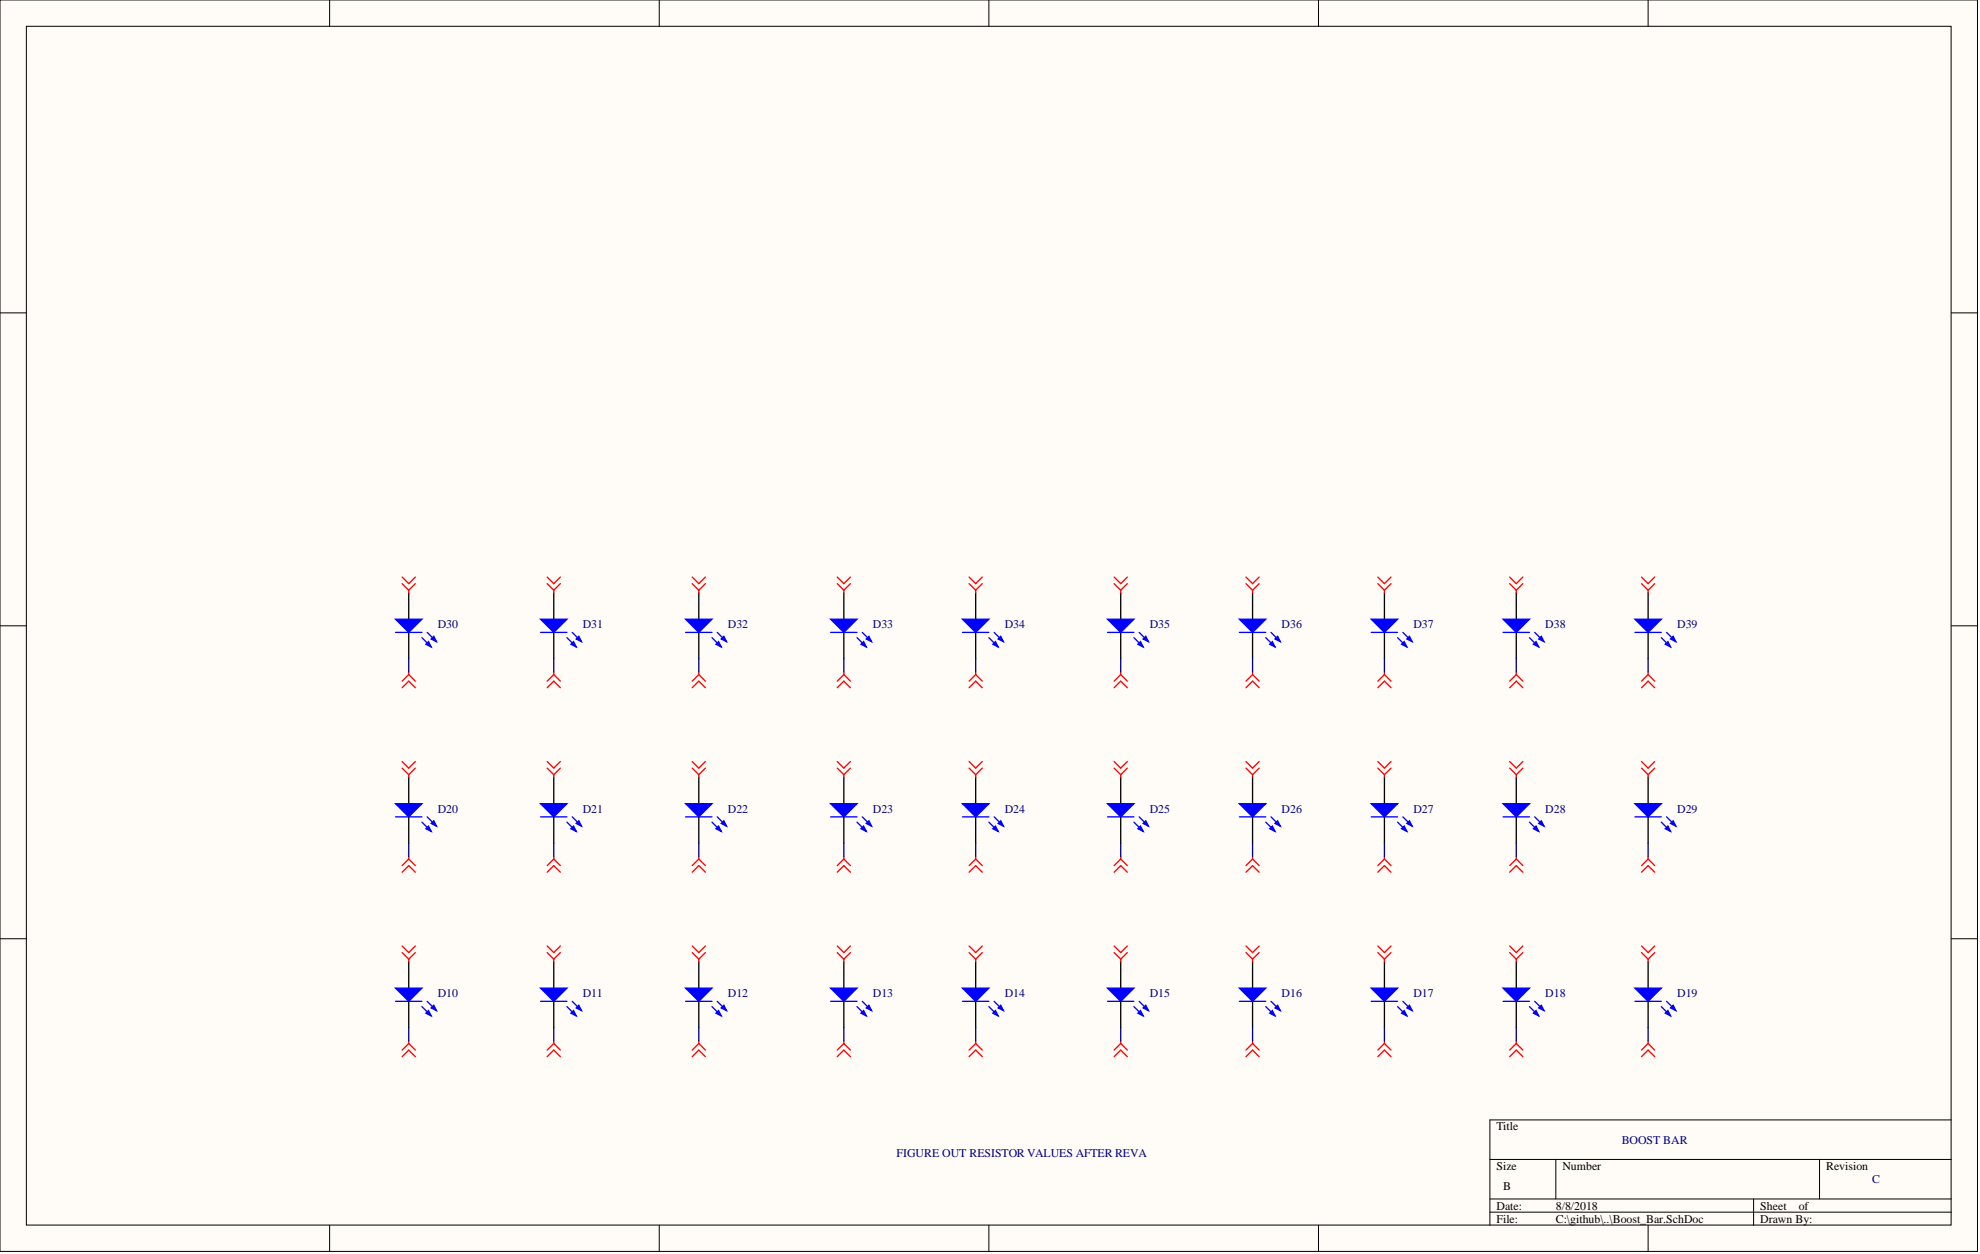
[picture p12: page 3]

FIGURE OUT RESISTOR VALUES AFTER REV

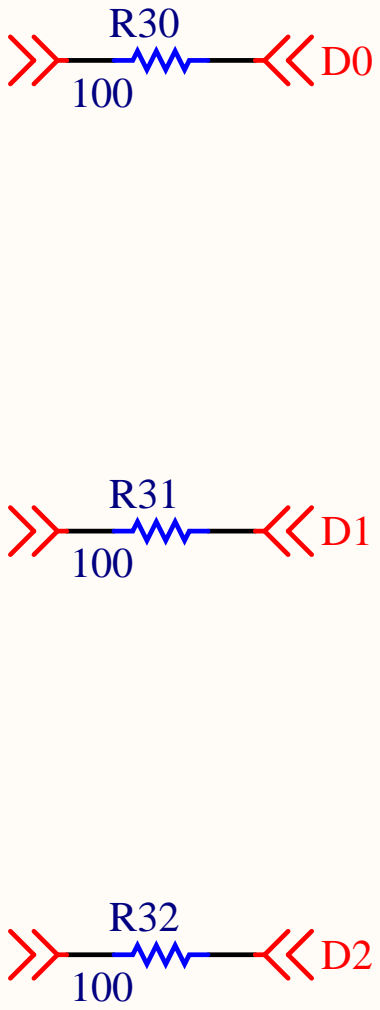
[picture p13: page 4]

BOOST BAR TERMINATION RESISTORS

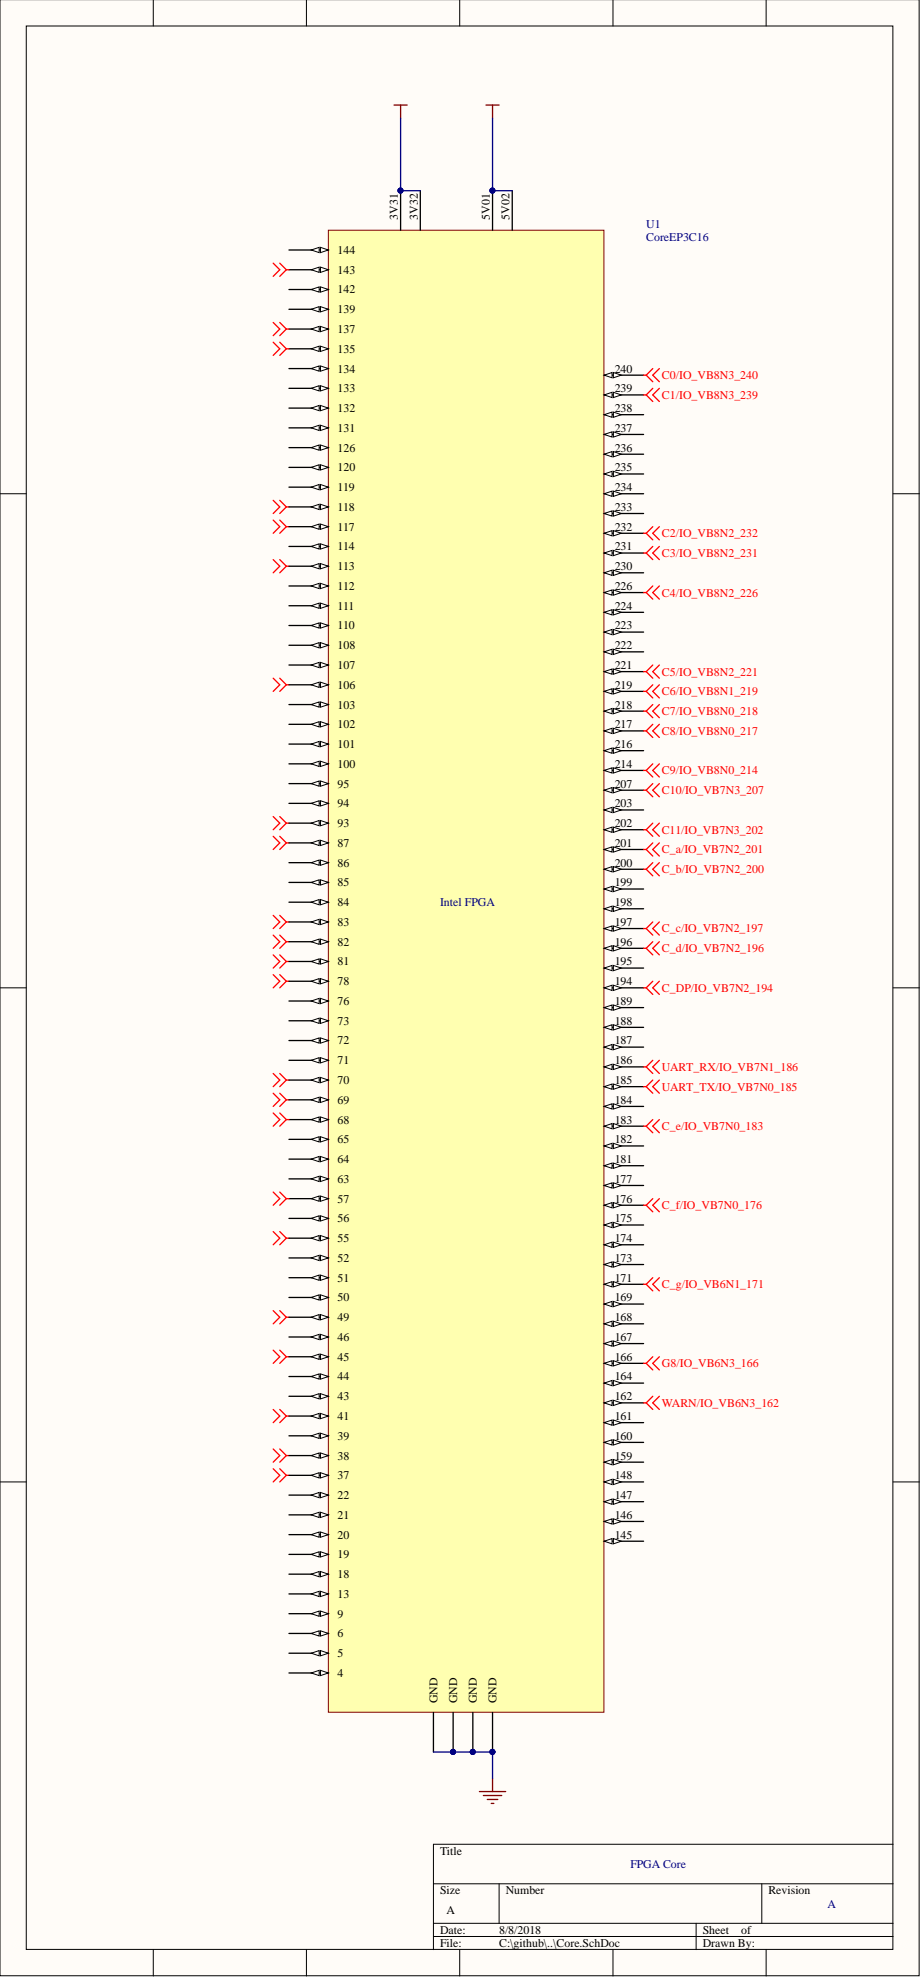
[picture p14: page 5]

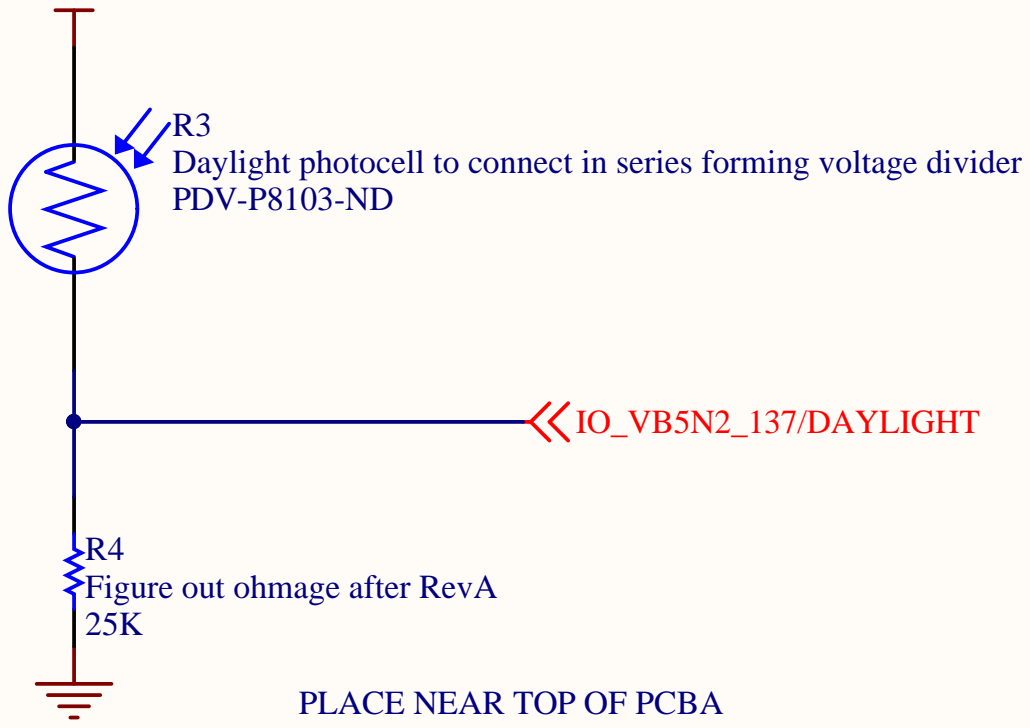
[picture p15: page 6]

Daylight photocell to connect in series forming voltage divider
PDV-P8103-ND

PLACE NEAR TOP OF PCBA

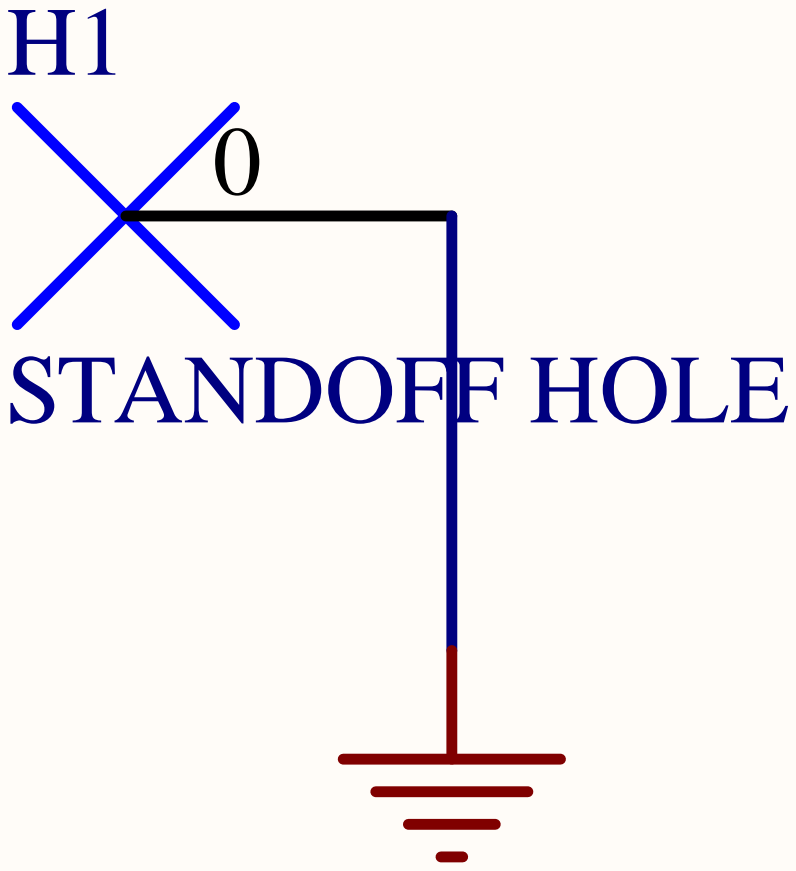
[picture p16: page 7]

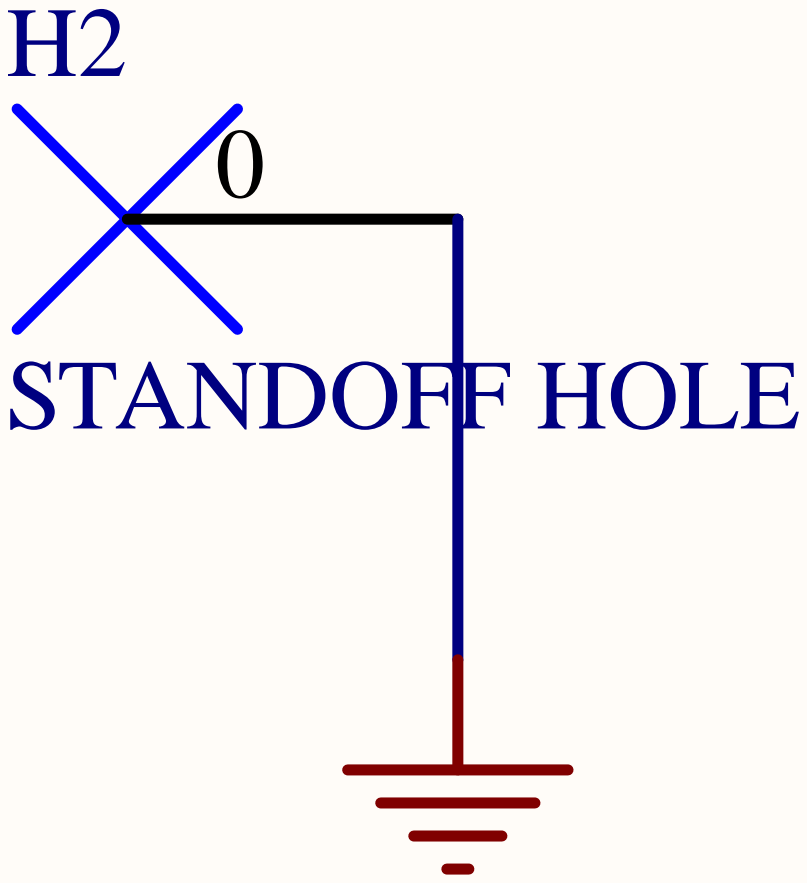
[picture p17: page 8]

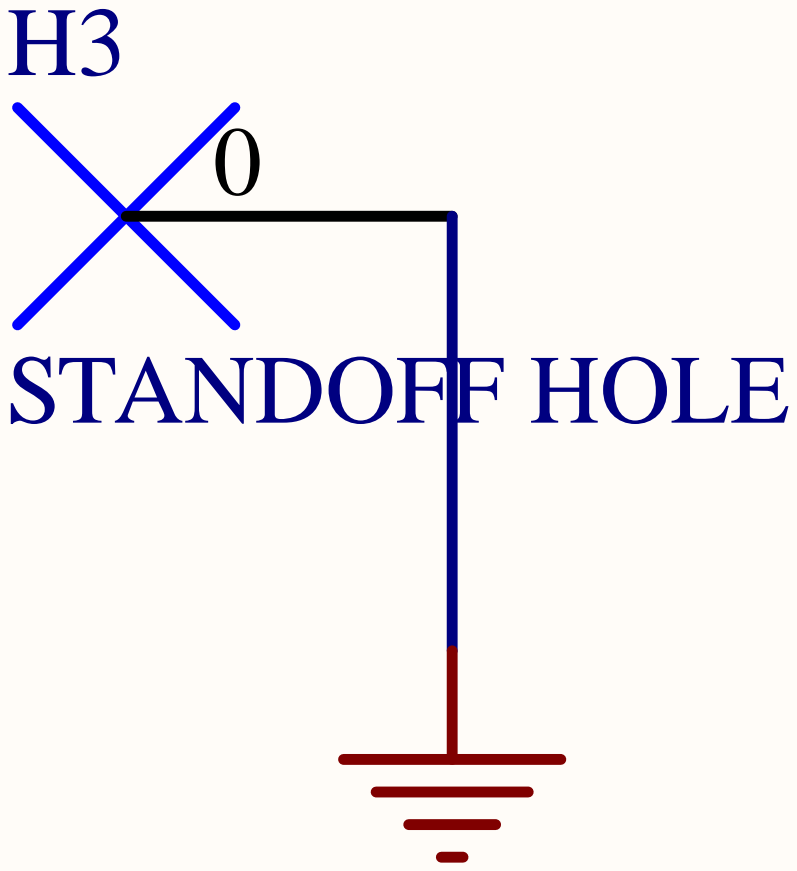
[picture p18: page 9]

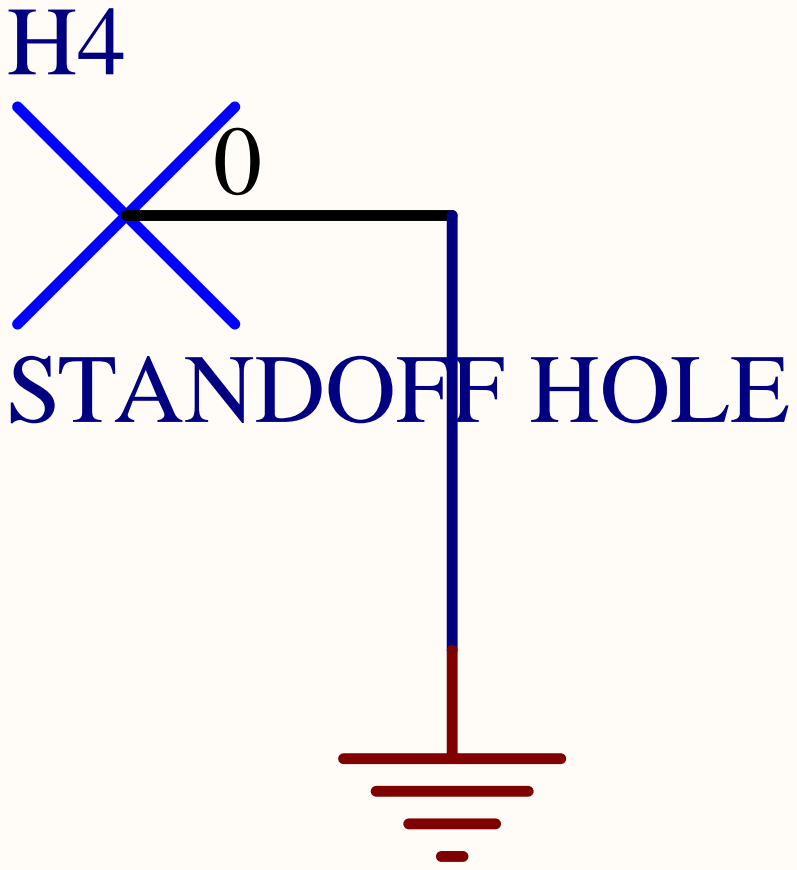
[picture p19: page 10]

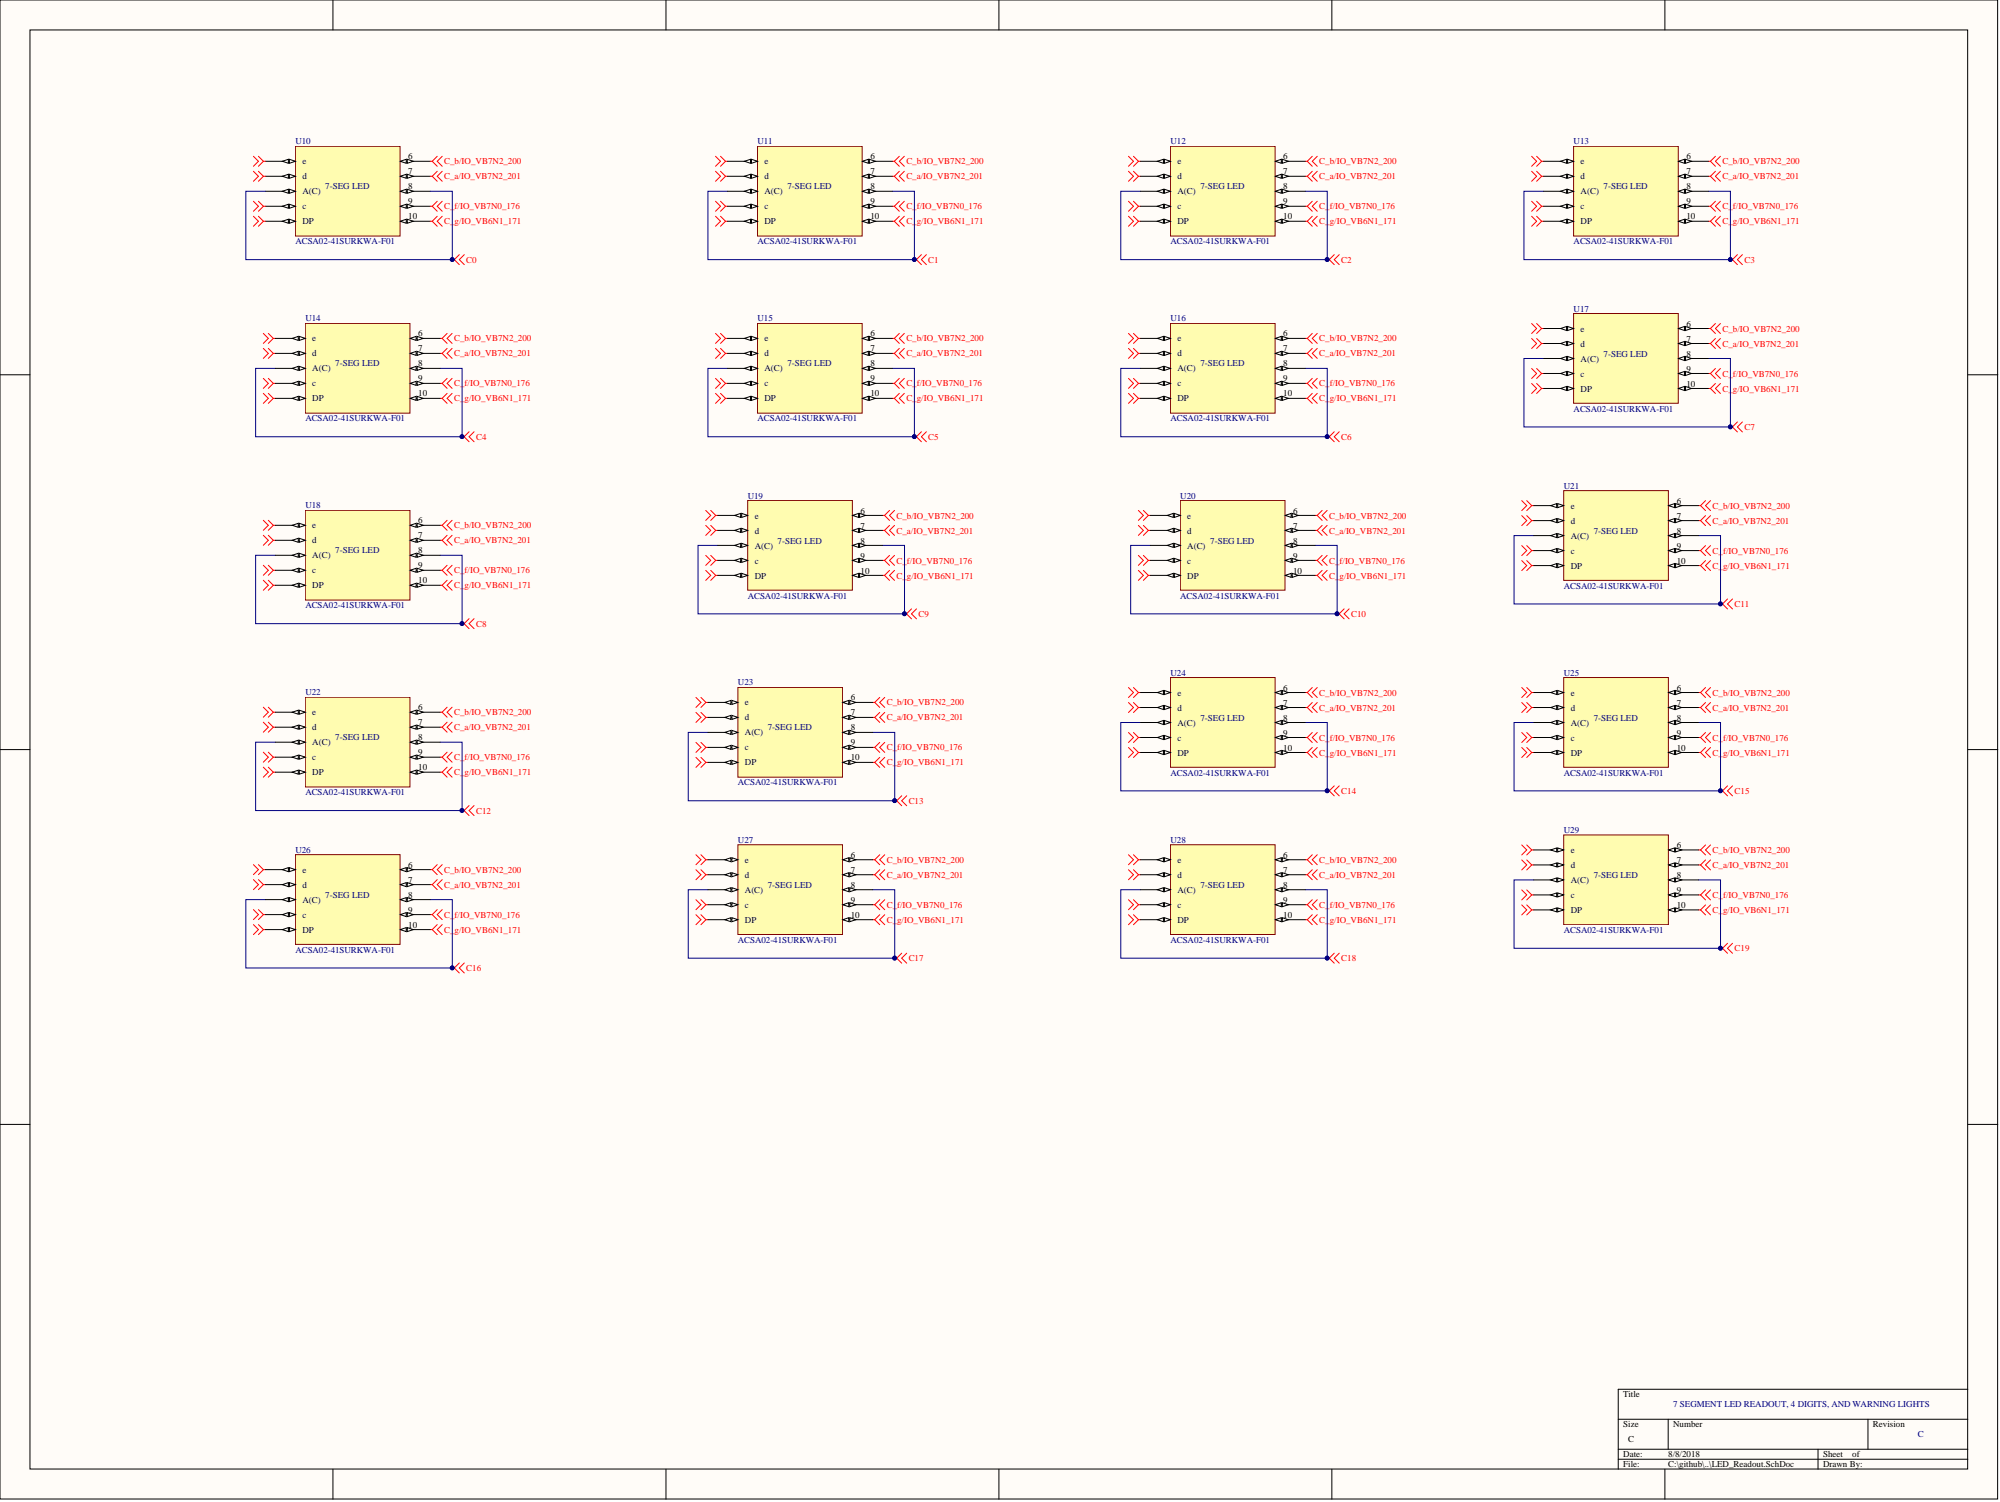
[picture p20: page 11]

7 SEGMENT LED READOUT, 4 DIGITS, AND WARNING LIGHTS C

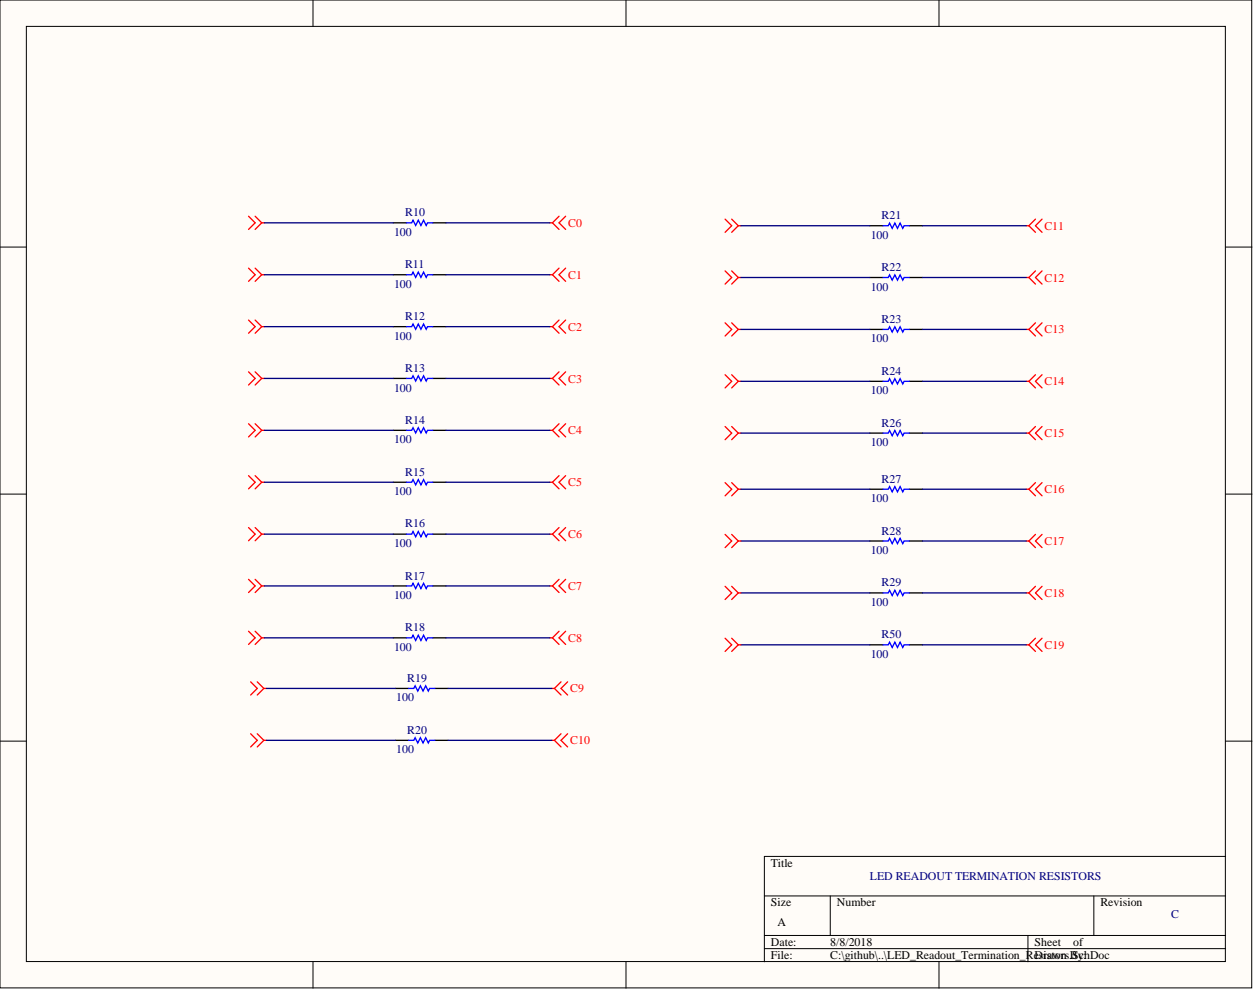
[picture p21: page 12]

LED READOUT TERMINATION RESISTORS


CONN HEADER R/A SGL 4POS GOLD (display)

PLACE NEAR BOTTOM OF PCBA


PLACE NEAR BOTTOM RIGHT



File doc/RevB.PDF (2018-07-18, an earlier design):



AFR BAR TERMINATION RESISTORS


FIGURE OUT RESISTOR VALUES AFTER REV


BOOST BAR TERMINATION RESISTORS



Daylight photocell to connect in series forming voltage divider
PDV-P8103-ND

PLACE NEAR TOP OF PCBA


Pull out some references to make probing easier





PLACE NEAR BOTTOM RIGHT

FIGURE OUT RESISTOR VALUES AFTER REVA

7 SEGMENT LED READOUT, 4 DIGITS, AND WARNING LIGHTS


7 SEGMENT LED READOUT, 4 DIGITS, AND WARNING LIGHTS TERMINATION RESISTORS B


CONN HEADER R/A SGL 4POS GOLD (display)

PLACE NEAR BOTTOM OF PCBA


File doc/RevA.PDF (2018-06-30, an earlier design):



AFR BAR TERMINATION RESISTORS


FIGURE OUT RESISTOR VALUES AFTER REV


BOOST BAR TERMINATION RESISTORS







PLACE NEAR BOTTOM RIGHT

FIGURE OUT RESISTOR VALUES AFTER REVA

7 SEGMENT LED READOUT, 4 DIGITS, AND WARNING LIGHTS


7 SEGMENT LED READOUT, 4 DIGITS, AND WARNING LIGHTS TERMINATION RESISTORS A


Figure out ohmage after RevA
NOSTUFF

CONN HEADER R/A SGL 4POS GOLD (display)

PLACE NEAR BOTTOM OF PCBA

Daylight photocell to connect in series forming voltage divider
PDV-P8103-ND

PLACE NEAR TOP OF PCBA

UART AND DAYLIGHT NETWORK


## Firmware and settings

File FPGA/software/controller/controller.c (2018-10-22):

/* 
 * Controller entry point.
 * 
 * Implements OBD2 gauge controller state machine.
 *
 */

#include "sys/alt_stdio.h"
#include "system.h"
#include "altera_avalon_pio_regs.h"
#include "controller_system.h"
#include "controller.h"
#include "uart.h"
#include "obd2.h"
#include "display.h"
#include <stdbool.h>
#include <string.h>

static void init();
#ifndef TEST
static void coroutine_entry();
#endif // TEST
static void shutdown();

int main()
{
	init();

	alt_putstr("Entering event loop\n");

#ifdef TEST
	test();
#else
	coroutine_entry();
#endif // TEST
	alt_putstr("Shutting down\n");
	shutdown();
	return 0;
}

void wait_tick(dword_t ticks)
{
	if (ticks > 0)
	{
		dword_t start = tc_get_ticks(TC_TICK_COUNTER);
		dword_t end = start + ticks;
		if (end < start)
		{
			// Overflow wrap
			while (tc_get_ticks(TC_TICK_COUNTER) < TC_MAX)
			{
				nop();
			}
		}

		while (tc_get_ticks(TC_TICK_COUNTER) < end)
		{
			nop();
		}
	}
}

bool is_frame()
{
	// Meant to be called once per event loop iteration, otherwise you will see weird behavior.
	dword_t frame = tc_get_ticks(TC_FRAME_COUNTER);
	if (frame > 0)
	{
		tc_reset(TC_FRAME_COUNTER);
		return true;
	}
	else
	{
		return false;
	}
}

void init()
{
	int rc;

	led_set_period(8000);
	status_led_enable(true);
	bcd_init();
	sseg_init();
	leds_init(LedArray1);
	leds_init(LedArray2);
	tc_init();
	warn_init();

	// Configure the timer counters for the controller
	tc_set_max(TC_TICK_COUNTER, 1000000U / CLOCK_PERIOD_NS); // 1 ms per tick
	tc_set_max(TC_FRAME_COUNTER, 8000000U / CLOCK_PERIOD_NS); // 8 ms per tick

	// The OBD2 UART is 3.3v, 115200, 8 data, 1 stop, no parity check
	rc = uart_open(UART_DBIT_8, UART_SBIT_ONE, UART_PARITY_NONE, 115200);
	if (0 > rc)
	{
		alt_printf("uart_config failed: %d (%s)\n", rc, uart_etos(rc));
	}

#ifndef TEST
	// Init business logic coroutines.
	obd2_init();
#endif // TEST
}

void shutdown()
{
	static const dword_t ResetTicks = CLOCK_MILLIS_TO_TICKS(5000);

#ifndef TEST
	// Shutdown business logic coroutines.
	obd2_shutdown();
#endif // TEST
	// Shutdown everything and go into a low power state for a few thousand MS.
	bcd_shutdown();
	sseg_shutdown();
	leds_shutdown(LedArray2);
	leds_shutdown(LedArray1);
	tc_shutdown();
	warn_shutdown();
	uart_close(UART_FLAG_SYNC);
	status_led_off(STATUS_LED_0 | STATUS_LED_1 | STATUS_LED_2 | STATUS_LED_3);
	status_led_enable(false);
	rc_reset(ResetTicks);
}

#ifndef TEST

void coroutine_entry()
{
	// Entry point for coroutine manager.

	bool display_initialized = false;

	for (;;)
	{
		// OBD2 update.
		if (!obd2_update())
		{
			alt_putstr("Terminating coroutines based on OBD2 state.\n");
			break;
		}

		if (Obd2StateReset != obd2_state)
		{
			if (!display_initialized)
			{
				display_initialized = true;
				display_init();
			}

			if (is_frame())
			{
				display_update();
			}
		}

		wait_tick(1);
	}
}

#endif // TEST

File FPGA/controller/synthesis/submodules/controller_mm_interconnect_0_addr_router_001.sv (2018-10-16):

// (C) 2001-2013 Altera Corporation. All rights reserved.
// Your use of Altera Corporation's design tools, logic functions and other 
// software and tools, and its AMPP partner logic functions, and any output 
// files any of the foregoing (including device programming or simulation 
// files), and any associated documentation or information are expressly subject 
// to the terms and conditions of the Altera Program License Subscription 
// Agreement, Altera MegaCore Function License Agreement, or other applicable 
// license agreement, including, without limitation, that your use is for the 
// sole purpose of programming logic devices manufactured by Altera and sold by 
// Altera or its authorized distributors.  Please refer to the applicable 
// agreement for further details.


// (C) 2001-2013 Altera Corporation. All rights reserved.
// Your use of Altera Corporation's design tools, logic functions and other 
// software and tools, and its AMPP partner logic functions, and any output 
// files any of the foregoing (including device programming or simulation 
// files), and any associated documentation or information are expressly subject 
// to the terms and conditions of the Altera Program License Subscription 
// Agreement, Altera MegaCore Function License Agreement, or other applicable 
// license agreement, including, without limitation, that your use is for the 
// sole purpose of programming logic devices manufactured by Altera and sold by 
// Altera or its authorized distributors.  Please refer to the applicable 
// agreement for further details.


// $Id: //acds/rel/13.1/ip/merlin/altera_merlin_router/altera_merlin_router.sv.terp#5 $
// $Revision: #5 $
// $Date: 2013/09/30 $
// $Author: perforce $

// -------------------------------------------------------
// Merlin Router
//
// Asserts the appropriate one-hot encoded channel based on 
// either (a) the address or (b) the dest id. The DECODER_TYPE
// parameter controls this behaviour. 0 means address decoder,
// 1 means dest id decoder.
//
// In the case of (a), it also sets the destination id.
// -------------------------------------------------------

`timescale 1 ns / 1 ns

module controller_mm_interconnect_0_addr_router_001_default_decode
  #(
     parameter DEFAULT_CHANNEL = 1,
               DEFAULT_WR_CHANNEL = -1,
               DEFAULT_RD_CHANNEL = -1,
               DEFAULT_DESTID = 19 
   )
  (output [85 - 80 : 0] default_destination_id,
   output [49-1 : 0] default_wr_channel,
   output [49-1 : 0] default_rd_channel,
   output [49-1 : 0] default_src_channel
  );

  assign default_destination_id = 
    DEFAULT_DESTID[85 - 80 : 0];

  generate begin : default_decode
    if (DEFAULT_CHANNEL == -1) begin
      assign default_src_channel = '0;
    end
    else begin
      assign default_src_channel = 49'b1 << DEFAULT_CHANNEL;
    end
  end
  endgenerate

  generate begin : default_decode_rw
    if (DEFAULT_RD_CHANNEL == -1) begin
      assign default_wr_channel = '0;
      assign default_rd_channel = '0;
    end
    else begin
      assign default_wr_channel = 49'b1 << DEFAULT_WR_CHANNEL;
      assign default_rd_channel = 49'b1 << DEFAULT_RD_CHANNEL;
    end
  end
  endgenerate

endmodule


module controller_mm_interconnect_0_addr_router_001
(
    // -------------------
    // Clock & Reset
    // -------------------
    input clk,
    input reset,

    // -------------------
    // Command Sink (Input)
    // -------------------
    input                       sink_valid,
    input  [99-1 : 0]    sink_data,
    input                       sink_startofpacket,
    input                       sink_endofpacket,
    output                      sink_ready,

    // -------------------
    // Command Source (Output)
    // -------------------
    output                          src_valid,
    output reg [99-1    : 0] src_data,
    output reg [49-1 : 0] src_channel,
    output                          src_startofpacket,
    output                          src_endofpacket,
    input                           src_ready
);

    // -------------------------------------------------------
    // Local parameters and variables
    // -------------------------------------------------------
    localparam PKT_ADDR_H = 52;
    localparam PKT_ADDR_L = 36;
    localparam PKT_DEST_ID_H = 85;
    localparam PKT_DEST_ID_L = 80;
    localparam PKT_PROTECTION_H = 89;
    localparam PKT_PROTECTION_L = 87;
    localparam ST_DATA_W = 99;
    localparam ST_CHANNEL_W = 49;
    localparam DECODER_TYPE = 0;

    localparam PKT_TRANS_WRITE = 55;
    localparam PKT_TRANS_READ  = 56;

    localparam PKT_ADDR_W = PKT_ADDR_H-PKT_ADDR_L + 1;
    localparam PKT_DEST_ID_W = PKT_DEST_ID_H-PKT_DEST_ID_L + 1;
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

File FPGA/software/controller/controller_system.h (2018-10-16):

/*
 * controller_system.h
 * 
 * Header file for system routines for the soft MCU. Mostly contains C 
 * implementations of testbench functionality.
 *
 */

#pragma once

#include <stdbool.h>

typedef unsigned char byte_t;
typedef unsigned short word_t;
typedef unsigned int dword_t;

// Defines the clock period
#define CLOCK_SPEED_HZ           ((dword_t)50000000)                         // ex 50Mhz
#define CLOCK_PERIOD_NS          ((dword_t)20)                               // 20ns per 50mhz clock
#define CLOCK_MILLIS_TO_TICKS(X) (((dword_t)X * 1000000U) / CLOCK_PERIOD_NS)

// Delays for one clock period
static inline void nop(void)
{
	__asm__ ("nop");
}

/*
 * BCD module control
 */

#define BCD_MAX 4

#define BCD1_CONTROL_START    (1 << 0)
#define BCD1_CONTROL_TC_RESET (1 << 1)
#define BCD1_CONTROL_RESET    (1 << 2)

#define BCD1_STATUS_COUNTER_OF (1 << 0)
#define BCD1_STATUS_READY      (1 << 1)

// Converts a binary value into BCD
void bcd_convert(dword_t bin, byte_t bcd[BCD_MAX]);

// Initialize and reset the BCD module
void bcd_init(void);

// Shutdown the BCD module, holding it in reset
void bcd_shutdown(void);

/*
 * Daylight sensor control
 */

// Returns true if daylight is detected
bool is_daylight(void);

/*
 * LED array control
 */

typedef enum LedArray_t
{
	LedArray1 = 0,
	LedArray2 = 1
} LedArray;

#define LEDS_MAX 30 // Maximum LED strip LEDs

#define LEDS_COUNTER_RESET   (1 << 0)
#define LEDS_RESET           (1 << 1)

#define LEDS_N_BITS 4
#define LEDS_M_BITS 4
#define LEDS_ADDR_W (LEDS_N_BITS + LEDS_M_BITS)

#define LEDS_N_MASK ((1 << LEDS_N_BITS) - 1)
#define LEDS_M_MASK ((1 << LEDS_M_BITS) - 1)
#define LEDS_ADDR_MASK ((1 << LEDS_ADDR_W) - 1)

#define LEDS_CONTROL_EN_IDX LEDS_ADDR_W
#define LEDS_CONTROL_SEL_IDX (LEDS_ADDR_W + 1)

#define LEDS_CONTROL_EN  (1 << LEDS_CONTROL_EN_IDX)
#define LEDS_CONTROL_SEL (1 << LEDS_CONTROL_SEL_IDX)

#define LEDS_BRIGHTNESS_MAX 0xFF

// Control LED brightness
void leds_set_brightness(LedArray arr, byte_t brightness);

// Enable or disable an LED
void leds_enable_led(LedArray arr, dword_t addr, bool en);

// Initialize and reset the LED module
void leds_init(LedArray arr);

// Shutdown the LED module, holding it in reset
void leds_shutdown(LedArray arr);

/*
 * SSEG array control
 */

#define SSEG_MAX 20

#define SSEG_COUNTER_RESET  (1 << 0)
#define SSEG_RESET          (1 << 1)

#define SSEG_VAL_BITS 4
#define SSEG_SEL_BITS 5

#define SSEG_SEL_MASK ((1 << SSEG_SEL_BITS) - 1)
#define SSEG_VAL_MASK ((1 << SSEG_VAL_BITS) - 1)

#define SSEG_WR_IDX     (SSEG_SEL_BITS + SSEG_VAL_BITS + 3)
#define SSEG_SEL_IDX    (SSEG_VAL_BITS + 3)
#define SSEG_VAL_EN_IDX (SSEG_VAL_BITS + 2)
#define SSEG_SIGN_IDX   (SSEG_VAL_BITS + 1)
#define SSEG_DP_IDX     (SSEG_VAL_BITS)

#define SSEG_WR     (1 << SSEG_WR_IDX)
#define SSEG_SEL    (1 << SSEG_SEL_IDX)
#define SSEG_VAL_EN (1 << SSEG_VAL_EN_IDX)
#define SSEG_SIGN   (1 << SSEG_SIGN_IDX)
#define SSEG_DP     (1 << SSEG_DP_IDX)


#define SSEG_BRIGHTNESS_MAX 0xFF

// Control SSEG brightness
void sseg_set_brightness(byte_t brightness);

// Initialize the SSEG module
void sseg_init(void);

// Shutdown the SSEG module, holding it in reset
void sseg_shutdown(void);

// Set a BCD value using SsegVal to construct val
void sseg_set_bcd(dword_t addr, dword_t flags, dword_t val);

/*
 * Status LED control
 */

#define STATUS_LED_IDX(X) (1 << X)
#define STATUS_LED_0 STATUS_LED_IDX(0)
#define STATUS_LED_1 STATUS_LED_IDX(1)
#define STATUS_LED_2 STATUS_LED_IDX(2)
#define STATUS_LED_3 STATUS_LED_IDX(3)

// Enable or disable LEDS by max
void status_led_enable(bool en);
void status_led_on(dword_t mask);
void status_led_off(dword_t mask);

/*
 * Timer counter control
 */

#define TC_RESET_TC1 (1 << 0)
#define TC_RESET_TC2 (1 << 1)
#define TC_RESET_TC3 (1 << 2)
#define TC_RESET_TC4 (1 << 3)

#define TC_STATUS_COUNTER (1 << 0)
#define TC_STATUS_OF      (1 << 25)

#define TC_MAX (dword_t)((1 << 24) - 1)

typedef enum TcArray_t
{
	Tc1 = 0,
	Tc2 = 1,
	Tc3 = 2,
	Tc4 = 3
} TcArray;

// Set the clock maximum after which the counter is incremented
void tc_set_max(TcArray tc, dword_t m);

// Get the TC tick count
dword_t tc_get_ticks(TcArray tc);

// Get the TC overflow status
bool tc_get_of(TcArray tc);

// Reset the TC
void tc_reset(TcArray tc);

// Initialize the TC array
void tc_init(void);

// Shutdown the TC array, holding it in reset
void tc_shutdown(void);

/*
 * UART1 control
 */

#define UART_OS_MAX   ((dword_t)(1 << 8) - 1)
#define UART_DVSR_BIT ((dword_t)UART1_DVSR_DATA_WIDTH)
#define UART_DBIT_BIT ((dword_t)8

#define UART1_RESET_TX_TC (1 << 0)
#define UART1_RESET_RX_TC (1 << 1)
#define UART1_RESET       (1 << 2)

#define UART1_WR_CONTROL_WR (1 << 0)
#define UART1_WR_CONTROL_RD (1 << 1)

#define UART1_STATUS_TX_COUNTER_OF (1 << 0)
#define UART1_STATUS_RX_COUNTER_OF (1 << 1)
#define UART1_STATUS_E_TXOF        (1 << 2)
#define UART1_STATUS_E_RXOF        (1 << 3)
#define UART1_STATUS_E_FRAME       (1 << 4)
#define UART1_STATUS_E_PARITY      (1 << 5)
#define UART1_STATUS_RX_EMPTY      (1 << 6)
#define UART1_STATUS_TX_FULL       (1 << 7)
#define UART1_STATUS_RX_FULL       (1 << 8)
#define UART1_STATUS_TX_EMPTY      (1 << 9)

// Sets the baud rate; data bit, parity bit, clock ticks for stop bit, clock ticks for overscan ratio, and baud divisor int(50M/(os_tick * baud rate))
void uart1_init(byte_t dbit, byte_t pbit, byte_t sb_tick, byte_t os_tick, word_t dvsr);

// Explicitly reset the UART, clearing internal FIFO and state
void uart1_reset(void);

// Shuts down the UART, holding it in reset
void uart1_shutdown(void);

// Reads from the RX FIFO, blocking until the RX buffer is ready
int uart1_rx(void);

// Adds data to the TX FIFO, waiting for the FIFO to clear if full
void uart1_tx(char data);

// Reads values which can be masked by UART_STATUS
dword_t uart1_read_status(void);

// Debug print UART status
void uart1_print_status(dword_t status);

/*
 * Warning LED control
 */

#define WARN_PWM_CONTROL_EN    (1 << 0)
#define WARN_PWM_CONTROL_RESET (1 << 1)

#define WARN_BRIGHTNESS_MAX 0xFF

// Control Warning LED brightness
void warn_set_brightness(byte_t brightness);

// Set warning LED enable state
void warn_set_en(bool en);

// Initialize the warning LED PWM controller
void warn_init(void);

// Shutdown the warning LED PWM controller, holding it in reset
void warn_shutdown(void);

/*
 * Reset control
 */

#define RC_M_BITS 24

#define RC_CONTROL_START (1 << RC_M_BITS)

// Force the controller into reset, bringing it back up after counts
void rc_reset(dword_t counts);

/*
 * Global LED control
 */

#define LEDS_PERIOD_MAX (dword_t)((1 << 24) - 1)

// Set the LED transition period in clocks
void led_set_period(dword_t period);

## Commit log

2018-06-30 Add RevA
    [AFR_Bar_Termination_Resistors.SchDoc, AFR_bar.SchDoc, Boost_Bar.SchDoc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]
2018-06-30 Add some docs
    [CoreEP3C16.PcbDoc]
2018-06-30 Add schematic doc
2018-06-30 gerber out
    [RevA.PcbDoc]
2018-07-03 Add board outline
    [RevA.PcbDoc]
2018-07-03 Add pin assignments... hope they work
2018-07-11 Add controller BSP and Qsys stuff
    Just go with whatever is being output for now even though it seems way
    too big to actually fit in the iram.
    Hope it works!
    [alt_sys_init.c, controller_dram.v]
2018-07-16 Add LED light bar and make some schematic changes
    [AFR_Bar_Termination_Resistors.SchDoc, AFR_bar.SchDoc, Boost_Bar.SchDoc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]
2018-07-18 Add some design validation cases
    - Some of the pads are mismatched and I think that
    might be why the controller seems to die after a few ms.
    - The UART and sensor seem fine though.
    [Core.SchDoc, RevA.PcbDoc, footprints.PcbLib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]
2018-07-18 Fixes all the stuff I found wrong with RevA
    [Daylight_Sensor_Network.SchDoc, Debug.SchDoc, RevB.PcbDoc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]
2018-07-21 Support 115200 baud and fix a few UART bugs
2018-07-22 Revise LED bar into individually selectable LED matrix
2018-07-22 Add timer counter
2018-07-30 enable most LED circuitry to work
    [AFR_bar.SchDoc, Core.SchDoc, PCB_Project.PrjPcb]
2018-08-04 This gets the lighting mostly working
    [blastit_main.stp]
2018-08-06 Tweak the UART so it works in loop back
    Also make sure most of the other stuff works in the test panel
    [blastit_main.stp]
2018-08-07 The UART works
    [Uart.SchDoc]
2018-08-08 Submit RevC
    [AFR_Bar_Termination_Resistors.SchDoc, AFR_bar.SchDoc, Boost_Bar.SchDoc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]
2018-08-10 Add enclosure model and STL file
    It seems to fit fine, but it might need tweaks later on to stay on the
    build plate
    [Back.stl, Base.stl, Connector.stl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]
2018-08-24 Various changes
    Add more UART functionality and start with the reset and main loop
    routine behavior. Something is wrong with the UART but it's not my
    focus right now.
    Also add finalized enclosure back and connector pieces
    [Base.stl, Connector.stl, Enclosure.scad]
2018-09-18 Start on RevC bringup (switching to other laptop)
    [Core.SchDoc, Enclosure.scad, LED_Readout_Termination_Resistors.SchDoc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]
2018-09-20 Fixes enclosure to enclose around display
    The debug connector on the back actually interferes with the connector
    so in the design I just extended the viewpane. Woops!
    [Enclosure.scad, Viewpane.stl]
2018-10-16 Add echo tests
    Add sync and async line echo tests. Refactor UART code so it is somewhat
    more user friendly. Fix bug in UART fifo implementation so it actually
    works. Various other random changes.
    [controller.c, controller.h, controller_mm_interconnect_0_addr_router.sv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]
2018-10-17 Add FIFO OF/UF latch
    Also add OBD2 state machine test and clean up the UART module.
2018-10-22 Finalize OBD2 init code
    Finalize OBD2 init code with the right at commands for reset and shutdown.
    +Configure flash to run NIOS II code at boot so the device actually does stuff when you plug it in.
    +Fix some random warnings.
    [controller.c, controller.h, controller_mm_interconnect_0_id_router_001.sv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]
